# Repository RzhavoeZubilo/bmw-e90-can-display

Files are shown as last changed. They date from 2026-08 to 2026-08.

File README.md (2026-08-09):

# BMW E90 PT-CAN Display

Дополнительная приборка на Arduino Nano. Пассивно слушает моторную шину
PT-CAN и выводит на OLED температуры охлаждающей жидкости, масла двигателя и
**масла АКПП** и напряжение бортсети. При перегреве двигателя или коробки
мигает светодиодом и пищит.

## Целевая машина

**BMW E90 318i, 2011 (LCI), N46B20 бензин, АКПП ZF 6HP19.**

Что из этого следует:

- **N46 бензиновый → температура масла двигателя доступна.** Пустой байт `0xFF`
  в `0x1D0` — особенность дизелей N47, к вам не относится.
- **ZF 6HP19 совпадает с эталонным стендом**, с которого сняты захваты в
  DBC-mega-merge; эталонные логи сняты с E90 LCI — то же поколение.
- **2011 год → на контактах 6/14 колодки D-CAN**, а не PT-CAN. Переход
  произошёл около 03/2007. К PT-CAN подключаемся не через OBD (см. ниже).

## Быстрый старт

```bash
export PATH="$PATH:$HOME/.platformio/penv/bin"   # добавьте в ~/.zshrc
```

| Задача | Команда |
|---|---|
| Юнит-тесты на Mac (без железа) | `pio test -e native` |
| Сборка боевой прошивки | `pio run` |
| Прошивка | `pio run -t upload` |
| Разведка шины | `pio run -e sniffer -t upload` |
| Монитор порта | `pio device monitor` |
| Симулятор дисплея (картинка) | `./sim/build.sh` |

## Шины E90 и что на какой лежит

Три шины, на глаз неразличимые:

| Шина | Скорость | Что даёт |
|---|---|---|
| **PT-CAN** | 500 кбит/с | мотор, EGS, **температура масла АКПП** |
| K-CAN | 100 кбит/с | кузов, приборка, топливо по бакам, кнопки руля |
| D-CAN | 500 кбит/с | диагностика, молчит пока не спросят |

Устройство сделано под **PT-CAN**: только там вещается температура масла
коробки (`0x0B5`, сигнал `TEMP_GRB`). Подключение — два провода к CAN H и
CAN L в любом удобном месте: блок JBE, CAS, разъём у коробки.

| Параметр | Где | Состояние |
|---|---|---|
| Температура ОЖ | `0x1D0` B0 | работает |
| Температура масла двигателя | `0x1D0` B1 | работает (бензин) |
| **Температура масла АКПП** | `0x0B5` B7 | **работает** |
| Напряжение бортсети | `0x3B4` | работает |
| Температура впуска | не найдено на PT-CAN | **разведка** |
| Топливо | `0x349` — это K-CAN | **разведка** |

Топливо по бакам в литрах есть только на K-CAN, температуры впуска в нашем
DBC нет вообще. Места в вёрстке под оба параметра готовы и заняты прочерками.

### Как достать недостающее

На PT-CAN, помимо вещания, есть **адресный UDS-канал** к блокам напрямую:

| Блок | Запрос | Ответ |
|---|---|---|
| DME (двигатель) | `0x600` | `0x608` |
| EGS (ZF 6HP19) | `0x604` | `0x60C` |
| DSC (ABS) | `0x612` | `0x61A` |

Туда шлётся сервис UDS `0x22` с идентификатором данных. По DBC, `0x60C`
держит адаптации коробки и калибровки температуры ATF. Идентификаторы
публично не документированы — нащупываются сканером на живой машине.

## Разведка перед установкой

Пошаговая инструкция для работы на машине — от проверок на столе до
подключения к PT-CAN: **[docs/field-test.md](docs/field-test.md)**.

```bash
pio run -e sniffer -t upload && pio device monitor
```

Сканер дважды по 10 секунд слушает молча — на 100 и на 500 кбит/с, потому что
на неверной скорости любая шина выглядит немой. Затем печатает словарь ID и
сверяет его с маркерами известной принадлежности:

```
0x1D0   412   8B FF 6A C8 ...   <- [B] EngineData coolant/oil
0x0B5   205   00 00 .. .. 78    <- [P] EGS torque + ATF temp
markers: PT-CAN-only 1, K-CAN-only 0
=> PT-CAN. lib/PtCan decoders apply. ATF temp available.
```

`[P]` — только PT-CAN, `[K]` — только K-CAN, `[B]` — есть на обеих (DME
вещает, шлюз ретранслирует). Дальше свип стандартных PID `0x00..0xA0`.

## Структура

```
include/pins.h          распиновка, единственное место с номерами ног
lib/PtCan/              декодер PT-CAN — используется прошивкой
lib/Screen/             вёрстка экрана на C-API u8g2, общая с симулятором
lib/Alerts/             пороги предупреждений
lib/BtnLearn/           поиск кнопки руля в потоке кадров
lib/KCan/               декодер K-CAN — резерв, если переедем на кузовную шину
lib/Obd/                клиент OBD-II — резерв, если вернёмся к колодке
lib/Buttons/            антидребезг — резерв под кнопки
src/main.cpp            склейка железа: приём, отрисовка, индикация
src/sniffer.cpp         разведка шины и свип PID
docs/field-test.md      инструкция по разведке на машине
docs/enclosure.md       эскиз корпуса под 3D-печать
docs/wiring.md          распайка и порядок сборки
docs/components.md      справка по компонентам и работе с ними
docs/cluster-menu.md    скрытое меню приборки: что показывает штатно
docs/rad2-coding.md     магнитола RAD2: почему не кодируется, индексы
docs/references.md      внешние источники и что каждый дал
docs/diag-jobs.md       запросы к блокам, извлечённые из SP-Daten
tools/sgbd_extract.py   извлекатель телеграмм из SGBD
cad/enclosure.scad      параметрическая модель корпуса (OpenSCAD)
sim/                    симулятор дисплея для macOS
test/                   нативные тесты (49 шт.)
```

Всё, что имеет смысл тестировать, лежит в `lib/` и не зависит от Arduino,
поэтому `pio test -e native` выполняется прямо на Mac за пару секунд. `src/` —
тонкий слой поверх железа, он не тестируется.

`lib/KCan`, `lib/Obd` и `lib/Buttons` в текущую прошивку не линкуются и флеш
не занимают, но покрыты тестами и готовы к подключению.

### Откуда взяты определения сигналов

Из репозитория **DBC-mega-merge** (`bmw_e9x_e8x1_merged.dbc`), лежащего рядом
в `../DBC-mega-merge`. Это сведённый DBC по E8x/E9x, собранный из opendbc,
loopybunny.co.uk и форумных источников и дополненный захватами с живой машины
и HIL-стенда.

Кадры DME проверены тестами на **реальных байтах** из
`tools/known_values.json` — это самые частые значения из логов:

| Кадр | Захваченные байты | Результат декодера |
|---|---|---|
| `0x1D0` | `8B FF 6A C8 ...` | ОЖ 91 °C, масло отсутствует (`0xFF`, N47) |
| `0x3B4` | `CB F3 00 FC ...` | 14.57 В |

Кадр EGS `0x0B5` на K-CAN не выходит, поэтому байтов с живой машины у нас
нет: его декодер проверен **только по DBC** — разрядность, смещение и
формула. Это единственная непроверенная эмпирически часть.

Полезные соседи по теме [github.com/topics/e90](https://github.com/topics/e90):

| Репозиторий | Чем полезен |
|---|---|
| `veikkos/e90-can-cluster` | распиновка разъёма приборки, предупреждение про терминатор |
| `Maseg535/E90-and-e8x-DBC-mega-merge-project` | тот самый DBC, который мы используем |
| `ilicmiljan/open-can-controller` | управление приборкой E9x по K-CAN через KWP2000 |

## Распиновка

| Ножка | Назначение | Примечание |
|---|---|---|
| D2 | MCP2515 INT | нужен именно D2 или D3 (INT0/INT1) |
| D6 | WS2812B DIN | один диод |
| D9 | KY-006 зуммер | пассивный, работает через `tone()` |
| D10 | MCP2515 CS | |
| D11/D12/D13 | SPI MOSI/MISO/SCK | аппаратный SPI, не переназначить |
| A4 / A5 | I2C SDA / SCL | OLED, адрес 0x3C |
| D3, D4, D5, D7 | резерв под TTP-223 | не используется |

Питание: один Mini360 с 12 В бортсети на 5 В. Второй модуль, четыре кнопки,
четыре светодиода из пяти и BME280 — запас на будущее, в сборке не участвуют.

Полная распайка, цепочка питания и порядок первого включения —
**[docs/wiring.md](docs/wiring.md)**.

Компоновка в корпусе под 3D-печать — **[docs/enclosure.md](docs/enclosure.md)**:
план дна, разрез, крышка и настройки печати.

## Симулятор дисплея

```bash
./sim/build.sh          # -> sim/out/screens.png
```

Рисует все состояния экрана в картинку, без железа и без машины. Это не макет:
симулятор гоняет **тот же самый `lib/Screen`**, что и прошивка, поверх C-ядра
u8g2, собранного под macOS. Разъехаться с реальным выводом он не может по
построению.

На AVR u8g2 рисует по страницам в буфер на 128 байт, на хосте — в полный буфер
128×64, куда симулятор заглядывает напрямую. Дисплей и шина не нужны, колбэки
вывода заглушены. Дальше буфер раскрашивается по физическому делению матрицы:
строки 0–15 жёлтым, 16–63 синим.

Именно поэтому `lib/Screen` написан на **C-API u8g2**, а не на Arduino-обёртке
`U8g2lib.h`: C-ядро переносимо, а обёртка тянет за собой `Print` и весь
Arduino. Побочная выгода — форматирование чисел там сделано вручную, без
`sprintf`, который на AVR стоит около полутора килобайт.

Сценарии перечислены в `build_scenarios()` в `sim/sim_main.cpp`. Первая сборка
компилирует C-ядро u8g2 и кэширует объектники в `sim/out/`, дальше мгновенно.

## Грабли

Собрано по ходу разработки. Большинство пунктов стоили бы вечера отладки.

### Без аппаратных фильтров MCP2515 кадры теряются молча

PT-CAN на 500 кбит/с даёт порядка 1500–2000 кадров в секунду. У MCP2515 два
приёмных буфера, и Nano разгребает их по SPI — без фильтров переполнение
гарантировано, причём **без единого признака в логах**.

Прошивка настраивает маски `0x7FF` (точное совпадение всех 11 бит) и все шесть
фильтров. Нужных ID сейчас три, остальные фильтры дублируют последний: пустой
фильтр пропускал бы всё подряд. Три свободных — запас под то, что найдёт
разведка. Список в `kWanted` в `src/main.cpp`.

### FastLED.show() нельзя дёргать в каждом проходе loop()

На AVR `show()` запрещает прерывания на всё время передачи данных в ленту.
Если вызывать его безусловно каждый проход, процессор проводит с
запрещёнными прерываниями почти всё время. Последствия неочевидные и
неприятные: **начинает отставать `millis()`** — а на нём висит вся логика
протухания данных, — ломается `tone()`, которому нужен таймерный ISR, и
страдает приём по I2C.

Правильно — вызывать только при смене состояния светодиода. Мигание с
периодом 400 мс даёт пару вызовов в секунду вместо тысяч. Реализовано в
`update_alerts()` в `src/main.cpp` через сравнение с прошлым состоянием.

### Сторожевой таймер и загрузчик

`wdt_enable(WDTO_2S)` в конце `setup()`, `wdt_reset()` в начале `loop()`.
Устройство живёт в машине без присмотра, зависший блок там никто не
перезагрузит.

Работает это безопасно **только потому, что плата на новом загрузчике**
(Optiboot, `board = nanoatmega328new`): он сбрасывает флаг `WDRF` и снимает
таймер при старте. Со старым загрузчиком срабатывание сторожевого таймера
загоняло плату в бесконечную перезагрузку, и спасала только перепрошивка
программатором.

В `sniffer` сторожевой таймер намеренно не включён: его фазы переписи длятся
по 10 секунд в одном блокирующем цикле, и таймер пришлось бы сбрасывать
изнутри. Инструмент запускается под присмотром, смысла в нём нет.

### Терминатор 120 Ом на модуле MCP2515 надо снять

Дешёвые платы приходят с напаянным резистором 120 Ом между CAN H и CAN L. Он
нужен при построении шины с нуля и **вреден при подключении к существующей**:
у исправной шины уже есть два своих терминатора, суммарно 60 Ом. Третий
опускает сопротивление до 40 Ом, и связь начинает сыпаться.

Симптом коварный: работает «через раз» или падает при прогреве. Проверяется
мультиметром на обесточенном модуле между CAN H и CAN L — увидите ~120 Ом,
резистор надо выпаять (на части плат вместо него перемычка).

Источник: README проекта
[veikkos/e90-can-cluster](https://github.com/veikkos/e90-can-cluster) —
«There should NOT be 120 Ohm termination in the CAN bus adapter».

### mcp_can хочет `unsigned long`, а не `uint32_t`

`readMsgBuf()` объявлен как `readMsgBuf(INT32U *id, ...)`, где `INT32U` — это
`unsigned long`. На AVR `uint32_t` и `unsigned long` — один и тот же тип,
поэтому `uint32_t id` собирается без нареканий, **но**:

- IntelliSense в VS Code разбирает файл в модели хоста, где `uint32_t` это
  `unsigned int`, и ругается «нет перегрузки» при зелёном `pio run`;
- на STM32 и ESP32 `uint32_t` тоже `unsigned int`, и там это станет настоящей
  ошибкой компиляции.

Поэтому во всех вызовах переменная объявлена как `unsigned long`. Правка
`.vscode/c_cpp_properties.json` не помогает: файл генерируется заново.

### MCP2515: кварц 8 или 16 МГц

В `platformio.ini` стоит `-D MCP2515_CRYSTAL_MHZ=8`. Дешёвые платы выпускают
с обоими кварцами — **посмотрите маркировку на кристалле** и поправьте флаг.
При неверном значении тайминги бит-рейта считаются неправильно, и CAN либо не
поднимется, либо будет сыпать мусором.

### Байт масла двигателя может быть `0xFF`

На дизелях N47 `0x1D0` B1 всегда `0xFF`. Наивная формула `raw - 48` дала бы
207 °C и постоянную ложную тревогу перегрева, поэтому декодер это значение
отбрасывает. На вашем N46 байт должен быть живым.

### Жёлто-синий OLED: граница на строке 16

Двухцветность физическая, а не программная: строки 0–15 всегда жёлтые, 16–63
всегда синие, границу не подвинуть. Крупный шрифт, поставленный без учёта
этого, разрезается пополам и выглядит как брак.

Вёрстка это учитывает: жёлтая полоса отдана под статус, все данные лежат
целиком ниже строки 16, четыре строки с baseline 27 / 38 / 49 / 60.

### tone() и FastLED делят прерывания

`tone()` на AVR всегда занимает Timer2 независимо от выбранной ноги, а
`FastLED.show()` кратко запрещает прерывания. На одном диоде пауза мизерная,
но если услышите щелчки в писке — причина здесь.

### Mini360 настраивается до подключения нагрузки

Подстроечник выставляется **до** того, как к выходу подключена электроника.
Иначе на выходе может оказаться входное напряжение, и Nano вместе с дисплеем
уходит в утиль за секунду.

### Прочее

- Плата с TYPE-C и CH340 — почти всегда **new bootloader** (115200), отсюда
  `board = nanoatmega328new`. Со старым `nanoatmega328` прошивка не зальётся.
- Если порт не появляется в `ls /dev/cu.*`, нужен драйвер CH340:
  `brew install --cask wch-ch34x-usb-serial-driver`.
- Основная прошивка не открывает Serial и **ничего не передаёт в шину**
  (`MCP_LISTENONLY`). Для отладки пользуйтесь env `sniffer`.

## Память

```
RAM:   54.4% (1114 / 2048)
Flash: 60.5% (18580 / 30720)
```

Запаса ~12 КБ флеша. Полнокадровый режим U8g2 (буфер 1024 байта) на Nano не
помещается, поэтому используется page-режим: буфер 128 байт, отрисовка циклом
`firstPage()/nextPage()`.

### Что сколько стоит

Замерено на этом проекте, каждый пункт — отдельная сборка:

| Что | Flash |
|---|---|
| Библиотека FastLED | **3018 байт** |
| Печать `float` (`print(x, 1)`) | **758 байт** |
| Крупный шрифт `logisoso20_tn` | 402 байта |
| `Serial.begin()` | 106 байт |

FastLED — самый дорогой компонент, и это плата за **саму библиотеку**, а не за
диоды: каждый стоит 3 байта RAM, разница между одним и пятью — двенадцать
байт. Для единственного светодиода 3 КБ расточительно; альтернатива — ручной
бит-бэнг WS2812 примерно на 100 байт, но там критичные тайминги.

Печать float тянет `dtostrf`. В проекте она не используется: значения хранятся
целыми в десятых долях и печатаются вручную.

### Стоит ли покупать «расширение памяти»

**Нет — для этой задачи такого модуля не существует.** ATmega328P построен по
гарвардской архитектуре и выполняет код **только из внутренней флеш-памяти**.
SD-карта, EEPROM, SPI-флешка хранят *данные*, а не исполняемый код.

Если проект перерастёт 32 КБ, вариант один — сменить плату:

| Плата | Флеш / RAM | Что переделать |
|---|---|---|
| **Mega 2560 Pro Mini** | 256 КБ / 8 КБ | только номера ног, логика 5 В |
| **STM32F103 «Blue Pill»** | 64–128 КБ / 20 КБ | встроенный CAN, логика 3.3 В |
| **ESP32** | 4 МБ / 520 КБ | встроенный CAN, Wi-Fi, логика 3.3 В |

При нынешних 60 % это теоретически.

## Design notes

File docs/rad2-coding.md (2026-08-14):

# Магнитола RAD2: почему не кодируется через D-CAN

Тема соседняя с основным проектом — здесь про кодирование головного
устройства, а не про наш прибор. Лежит в этом репозитории, потому что
собрано теми же инструментами и по тем же данным.

**Блок:** BMW Radio Professional CD, `6512 9258170-01`, `BMWRCD 202-35`,
Bluetooth, Чехия, 04/2011. Машина: E90 318i 2011 LCI.

**Симптом:** `SG_CODIEREN` и даже `CODIERDATEN_LESEN` в NCS Expert падают с
«ошибка CABD! смотри CABI.ERR und ERROR.LOG». Считается, что блок кодируется
только через ICOM.

---

## ⚠️ Поправка: причина ошибки другая

Изначальный диагноз в этом документе — «CABD не находит `RAD2.C34`» — **был
неверным**. Реальный текст ошибки, полученный позже:

```
COAPI-2020: SG antwortet nicht
IFH-0009: SG nicht angeschlossen oder meldet sich nicht   RAD2
```

`SG antwortet nicht` — «блок не отвечает». `IFH-0009` — ошибка обработчика
интерфейса EDIABAS, означающая, что ответа от блока не пришло вовсе.

То есть это **отказ связи, а не разбора данных**. Строка «Ошибка в CABD» —
всего лишь обёртка NCS Expert; настоящая причина напечатана под ней. Отсюда
же объяснение, почему не нашёлся `CABI.ERR`: CABD не дошёл до сборки данных
и своей ошибки не создавал.

Определение семейства `RAD22.C34` ниже остаётся верным и пригодится, когда
связь заработает, — но причиной этой ошибки оно не было.

### Рабочая гипотеза

Головное устройство на E90 сидит на **K-CAN**, а не на диагностической
D-CAN, и доступ к нему идёт **через шлюз**. В каталоге SGBD рядом с
`RAD2.prg` лежит **`RAD2_GW.prg`** — суффикс `GW` почти наверняка означает
вариант, работающий через шлюз.

NCS Expert использовал `RAD2.PRG`. Если прямой вариант адресует блок так,
как работает только внутри K-CAN, а `_GW` идёт через шлюз, это ровно та
разница, которая объясняет «через ICOM работает, через D-CAN нет».

**Не проверено** — требует запуска на машине.

### Порядок проверки

1. **Убедиться, что интерфейс вообще жив.** Tool32, загрузить `KOMB87.prg`,
   выполнить `IDENT`. Ответил — кабель и EDIABAS исправны, проблема
   именно в RAD2.
2. **Попробовать `RAD2_GW.prg`** в Tool32, тот же `IDENT`. Ответил там, где
   `RAD2.prg` молчит — гипотеза подтверждена, и дальше вопрос лишь в том,
   чтобы указать этот SGBD в профиле NCS Expert.
3. Если молчат оба — магнитола в вашей конфигурации по D-CAN недостижима, и
   ICOM остаётся единственным путём.

Tool32 здесь удобнее NCS Expert тем, что SGBD выбирается вручную, а не
берётся из профиля.

Проверить, что зажигание включено и магнитола не спит, — обязательное
условие для всех трёх пунктов.

---

## Определение семейства данных

**Блок относится к семейству данных `RAD22`, а не `RAD2`.**

Трейс `FSW_PSW`, снятый через ICOM, прогнан через парсер данных кодирования
и сопоставлен со всеми 339 файлами `.Cxx` для кузова E89:

| Файл данных | Совпадение с трейсом |
|---|---|
| **`RAD22.C34`** | **81.4 %** |
| `RAD22.C32` | 73.5 % |
| `RAD22.C31` | 62.8 % |
| `RAD22.C33` | 61.9 % |
| `RAD22.C20` | 43.4 % |
| `RAD2.C03/04/50/51` | **ниже порога, в кандидаты не попали** |

Из 113 строк трейса 92 совпали с `RAD22.C34` по именам параметров; остальные
21 — это не параметры, а их значения (`E90_HIFI`, `E81_TOP_HIFI` и подобные),
которые в трейсе идут отдельными строками.

Иначе говоря: **это `RAD22` с индексом кодирования 34.**

### Почему тогда CABD

Файлы данных кодирования именуются `<семейство>.C<индекс>`. В каталоге лежат:

```
RAD2.C03   RAD2.C04   RAD2.C50   RAD2.C51
RAD22.C20  RAD22.C31  RAD22.C32  RAD22.C33  RAD22.C34
```

**`RAD2.C34` не существует.** Если NCS Expert выбирает для этого блока
семейство `RAD2` (по профилю или по имени SGBD — `RAD2.prg` в каталоге есть,
а `RAD22.prg` нет), то при индексе 34 он ищет несуществующий файл. CABD не
может собрать данные и падает.

### Почему это не про кабель

**ICOM против K+DCAN — разница транспорта, а не логики кодирования.** NCS
Expert работает через EDIABAS, а тот умеет оба интерфейса. Если бы дело было
в железе, ошибка была бы коммуникационной: нет ответа, таймаут.

Решающий довод: падает и `CODIERDATEN_LESEN`. Чтение безобидно, блок его не
запрещает. Значит отказывает не блок, а разбор данных **на компьютере**, до
всякого обмена с машиной. CABD — компонент ПК.

ICOM «работает» потому, что ISTA-P везёт свои данные и сам выбирает нужное
семейство.

---

## Что проверить на машине

1. **Прочитать `CABI.ERR` и `ERROR.LOG`.** Сообщение прямо на них указывает,
   и там обычно назван конкретный отсутствующий файл. Это подтвердит или
   опровергнет диагноз за минуту.
2. **Прочитать индекс кодирования блока** — job `C_CI_LESEN` через Tool32.
   Чтение, риска нет. Ожидаемое значение — 34.
3. **Проверить, какую версию SP-Daten видит NCS Expert.** На диске лежат
   67.1 и 69.0; `RAD22.C34` найден в 69.0.

Если `C_CI_LESEN` вернёт 34, а NCS Expert ищет `RAD2.C34` — диагноз
подтверждён, и вопрос сводится к тому, чтобы указать ему семейство `RAD22`.

---

## Расшифровка индексов кодирования

Индексы идут по возрастанию функциональности. Ниже — что добавляет каждый
следующий относительно предыдущего.

| Индекс | Опций | Что появляется |
|---|---|---|
| `RAD2.C03` | 55 | базовый набор |
| `RAD2.C04` | 57 | `M_GROUP`, `USB_RAD2` |
| `RAD2.C50` | 75 | гонги, `COUNTRYCODE_RADIO_2`, концепция микширования |
| `RAD2.C51` | 81 | `MCA`, `BASS_MSA`, навигационные уровни |
| `RAD22.C20` | 70 | маршрутизация звука, лимитеры, `AUX_RAD22` |
| `RAD22.C31` | 83 | **INBOX-группа**: Bluetooth, распознавание речи, `DAB_INBOX`, микрофон |
| `RAD22.C32` | 86 | `SECOND_USB`, `RAD22_MDRIVE`, параметры с суффиксом `_32` |
| `RAD22.C33` | 83 | вариант C32 с суффиксом `_B` вместо `_32` |
| **`RAD22.C34`** | **94** | `DAB_STANDARD_RAD` (DAB+), `CALL_WAITING_INBOX`, `FADER`, `COLORSWITCH_E84` |

Быстрые признаки принадлежности:

| Параметр | Встречается в |
|---|---|
| `BT_MODUL_INBOX_ON_OFF`, `MICROPHONE_INBOX`, `DAB_INBOX` | C31, C32, C33, C34 |
| `SECOND_USB` | C32, C34 |
| `DAB_STANDARD_RAD`, `CALL_WAITING_INBOX`, `COLORSWITCH_E84` | **только C34** |

В вашем трейсе есть `DAB_STANDARD_RAD = dab_plus`, `CALL_WAITING_INBOX` и
`SECOND_USB` — то есть однозначно **C34**, самый поздний индекс из
имеющихся. Что согласуется с датой выпуска 04/2011.

---

## Про вывод параметров на экран магнитолы

Ответ тот же, что был по приборке: **магнитола показывает только то, что
умеет её прошивка**, а кодирование лишь выбирает из готового набора. Вывести
туда наши значения — температуру масла АКПП, впуск — нельзя без правки
прошивки.

Штатные пункты (средний расход, забортная) включаются кодированием. В вашем
трейсе видны кандидаты:

| Параметр | Текущее значение |
|---|---|
| `CAR_COMP_ACTIVE` | `aktiv` |
| `V_INFO_RAD2` | `nicht_aktiv` |
| `MY_INFO_RAD2_20` | `nicht_aktiv` |

Что именно за ними стоит — надо смотреть в описании функций; имена
параметров в SWT-словарях даны без развёрнутых пояснений.

**Осторожно:** `20.00`-подобные параметры и всё, что меняет уровни и
лимитеры, — это запись в блок. Читать безопасно, писать нет, а у вас уже
есть рабочий путь через ICOM.

---

## Как воспроизвести разбор

```bash
cd /Users/densh/Work/Develop/BMW/BimmerDaten
python3 - <<'EOF'
import sys; sys.path.insert(0,'.')
from daten_parser import parse_trc, detect_module_from_trc
D = ".../BMW SP-Daten 69.0/E89/daten"
trc = parse_trc("путь/к/FSW_PSW.TRC")
for f, r in detect_module_from_trc(set(trc.keys()), D, ""):
    print(f, f"{r*100:.1f}%")
EOF
```

Парсер шумит в stderr на части посторонних файлов — это не мешает, вывод
берётся из stdout.

Словари имён: `SWTFSW03.dat` (функции) и `SWTPSW03.dat` (значения) в том же
каталоге `daten`.

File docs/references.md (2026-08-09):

# Внешние источники

Что использовано по ходу работы и что именно каждый источник дал. Полезно
тем, что видно, какие выводы подтверждены независимо, а какие держатся на
одном источнике.

---

## Данные о шине

### DBC-mega-merge

`github.com/Maseg535/E90-and-e8x-DBC-mega-merge-project`, клон лежит в
`../DBC-mega-merge`. Сведённый DBC по E8x/E9x: 386 сообщений, 430 сигналов,
плюс захваты с живой машины и HIL-стенда.

**Дал:** все определения в `lib/KCan` и `lib/PtCan`. Файл
`tools/known_values.json` содержит самые частые байты по каждому ID — на них
построены тесты декодеров.

**Ограничения:** 275 сообщений из 386 без единого сигнала; 104 ID встречаются
в логах, но в DBC отсутствуют вовсе. Сами логи в репозиторий не попали, есть
только выжимка, по которой нельзя восстановить ни периоды, ни корреляции.

### loopybunny.co.uk/CarPC

Справочник по K-CAN E90. **В DBC уже поглощён** — указан там источником
десяти сигналов, включая скорость, двери, климат, поворотники.

Отдельная страница про интерфейс конкретики не содержит: перечислены Arduino
и MCP2515, но ни распиновки, ни точек подключения, ни требований по
терминированию там нет.

### SP-Daten 69.0 + BimmerDaten

Заводские описания диагностики. Декодер `.prg` — `decoderPrg.py`, парсер
данных кодирования — `daten_parser.py`.

**Дал:** телеграммы запросов ко всем блокам (см. [diag-jobs.md](diag-jobs.md)),
подтверждение диапазона температуры ATF, диагноз проблемы с кодированием
магнитолы (см. [rad2-coding.md](rad2-coding.md)).

---

## Чужие устройства того же назначения

### Инструкция к серийному зеркалу-дисплею

Бумажная инструкция к готовому устройству для E9x/E7x/E8x.

**Дала:** точную точку подключения PT-CAN — блок **JBBF**, синяя фишка
**X14271**, контакт 1 = CAN H (синий/красный), контакт 2 = CAN L (красный).
Это то, чего не было ни в одном другом источнике.

Плюс идею обучения кнопки руля: устройство не знает ID заранее, а находит
его, наблюдая, какой бит меняется при удержании. Реализовано в `lib/BtnLearn`.

### veikkos/e90-can-cluster

`github.com/veikkos/e90-can-cluster` — Arduino, управляющий приборкой E90.

**Дал:** распиновку 18-контактного разъёма приборки (pin 6 CAN H, pin 7
CAN L, pin 9 12 В, pin 18 GND) и предупреждение про терминатор:
«There should NOT be 120 Ohm termination in the CAN bus adapter».

### Серия записей на drive2 (E90 2007, дизель M57)

Три записи одного автора: то же по смыслу устройство на ESP32, три итерации
от 2,4″ до 5″ дисплея DWIN.

**Подтверждает независимо:**

| Вывод | Как подтверждён |
|---|---|
| На OBD-разъёме широковещания нет | автор пришёл к тому же и ушёл к приборке |
| Две шины: K-CAN 100, PT-CAN 500 | названы прямо теми же цифрами |
| `0x3B4` = напряжение, первые 2 байта | совпадает с нашим декодером |
| Терминатор 120 Ом надо снимать | у него SN65HVD230 с выпаянным резистором |
| `0x2FC` двери | совпадает с DBC |

**Новое, чего у нас не было:**

- **Засыпание по шине.** Устройство включается по зажиганию и выключается,
  когда шина сообщает об отсутствии ключа. Лучше, чем искать цепь после
  зажигания — см. [wiring.md](wiring.md).
- **Многозначные ответы.** Он отмечает, что диагностические сообщения пакуют
  несколько параметров в один ответ, и за счёт этого держит ~30 параметров
  каждые 100 мс. Мы видели то же в SGBD: `STATUS_TANKINHALT` возвращает пять
  значений за один запрос.
- **K-line как параллельный канал** для того, чего нет в широковещании. Нам
  недоступен: у него машина 2007 года, на нашей 2011 K-line заменён на D-CAN
  (переход около 03/2007).

Точку подключения он искал долго — плафон салона, блок света, топливный
насос — и в итоге сел на комбинацию приборов. У нас эта задача решена
инструкцией к серийному устройству, точка известна сразу.

---

## Реверс прошивок приборки

`../прошивки приборок` — собственный проект владельца: разбор прошивок KOMBI
(Siemens VDO PL2, Fujitsu MB90F395HA, F2MC-16LX) с самописным
дизассемблером.

**Дал:** понимание, что прошивка приборки содержит авторитетные распаковщики
принимаемых ею кадров — найден распаковщик `0x1D2`. Это принципиально более
надёжный источник определений, чем корреляция по логам.

**Упирается в:** подпись флеша (`FLASH_SIGNATUR_PRUEFEN`), из-за которой
модифицированный образ обратно не зальётся. Отмечено самим автором как
нерешённое.

---

## Что подтверждено сколькими источниками

| Вывод | Источников |
|---|---|
| OBD-разъём не даёт широковещания | 3: DBC, инструкция, drive2 |
| Терминатор 120 Ом мешает | 2: veikkos, drive2 |
| `0x1D6` = кнопки руля | 3: DBC, SGBD DSC, drive2 (косвенно) |
| `0x3B4` = напряжение | 2: DBC (захваты), drive2 |
| Температура ATF в `0x0B5` | 2: DBC, SGBD ZF (диапазон) |
| Раскладка ответа DME на впуск | **0 — только вывод из порядка полей** |
| Кнопки руля доступны на PT-CAN | 1: SGBD DSC, на машине не проверено |

Последние две строки — то, что стоит проверить в первую очередь.

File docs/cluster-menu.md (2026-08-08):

# Скрытое меню приборки

Штатное сервисное меню KOMBI. Открывается удержанием кнопки сброса суточного
пробега при включённом зажигании; большинство разделов требует разблокировки
через пункт `19.00`, а тест индикации `02.00` доступен и без неё.

**Статус: большинство пунктов проверено владельцем на этой машине** (E90 318i
2011, N46B20, ZF 6HP19). Нумерация у разных комплектаций может отличаться.

---

## Почему это важно для проекта

Меню показывает **часть того же набора, что и наше устройство**, причём без
единого провода. Это меняет ответ на вопрос «зачем вообще нужен прибор».

| Пункт | Параметр | Есть ли у нас |
|---|---|---|
| `07.00 KTMP-MOM` | температура ОЖ | экран 2 |
| `06.00 TANK L R S` | топливо: левый, правый, сумма | **нет**, не смогли достать |
| `06.02 TANK-OHM L R` | сопротивления датчиков баков | нет |
| `09.00 UB` | напряжение бортсети | экран 3 |
| `07.01 ATMP-MOM` | забортная температура | нет |
| `07.03 N-MOT-MOM` | обороты | убрано намеренно |

### Чего в меню нет

**Температуры масла АКПП и температуры впуска.** Ни в одном пункте. Это
ровно то, что даёт устройство и не даёт машина.

Плюс постоянная видимость: меню нужно открывать и листать, а экран висит
перед глазами и сам пищит при перегреве. Но список, где устройство
действительно уникально, — два параметра, а не семь. Стоит понимать честно.

---

## ★ Калибровка баков

Мы отказались от чтения `STATUS_TANKINHALT` у приборки в том числе потому,
что **масштаб ответа неизвестен**: в SGBD у результатов написано просто
«Zahlenwert», а единица возвращается отдельной строкой во время выполнения
(см. [diag-jobs.md](diag-jobs.md)).

Меню эту неизвестность снимает. Пункты `06.00` и `06.02` показывают те же
датчики в литрах и в омах.

Процедура:

1. Открыть `06.00`, записать литры по левому и правому датчику.
2. Тут же отправить приборке `21 0A` и записать **сырой ответ**.
3. Повторить при заметно другом уровне топлива — две-три пары дадут и
   множитель, и смещение.

Одного замера хватит на множитель, если смещение нулевое; два замера решают
систему полностью. То есть блокирующая неизвестность устраняется за один
подход к машине — при условии, что до KOMBI получится дотянуться по шине,
а это отдельный вопрос (приборка на K-CAN).

---

## Прочее полезное

`02.00 KI TEST` — прогон стрелок и индикаторов, **доступен без
разблокировки**. Это та самая функция, которую серийное устройство из
инструкции подаёт как своё умение; на деле для неё ничего не нужно.

`15.xx PORT xxh` — значения портов контроллера в битах. Готовое окно в
состояние железа для разбора прошивки приборки.

`14.xx FSPxx` — записи в памяти ошибок, без диагностического сканера.

`20.00 KORR-VERBR` — коэффициент коррекции расхода. **Это запись, а не
чтение**: пункты `20.01`–`20.03` меняют значение по разрядам.

---

## Полный список

| Пункт | Обозначение | Что это |
|---|---|---|
| 01.00 | FGSTNR | VIN приборки |
| 01.01 | K-ZAHL W/T | корректировка пробега |
| 01.02 | BMWTNR | серийный номер приборки |
| 01.03 | COD DIA | код диагностики |
| 01.04 | KI HSTLDATUM | дата производства |
| 01.05 | HW AEI | версия железа |
| 01.06 | SW | версия прошивки |
| 01.07 | KODIERDATEN | данные кодирования |
| 01.08 | CAN | версия шины |
| **02.00** | **KI TEST** | **тест индикации, без разблокировки** |
| 03.00 | UNBELEGT | не используется |
| 04.00 | VERB-MOM | мгновенный расход, л/100 км |
| 04.01 | VERB-MOM | мгновенный расход, л/час |
| 04.02–04.05 | D-VERB1/2 | средний расход и дистанция поездок |
| 05.00 | RW-VERB | средний расход для запаса хода |
| 05.01 | RW-MOM | запас хода |
| **06.00** | **TANK L R S** | **топливо: левый, правый, сумма** |
| 06.01 | TANK-ANZ PH | общее количество в баке |
| **06.02** | **TANK-OHM L R** | **сопротивления датчиков, Ом** |
| **07.00** | **KTMP-MOM** | **температура ОЖ** |
| 07.01 | ATMP-MOM | забортная температура |
| 07.02 | ATMP ADC | сырое значение датчика забортной |
| 07.03 | N-MOT-MOM | обороты двигателя |
| 07.04 | N-VWF-MOM | ограничитель оборотов при прогреве, M-серия |
| 08.00 | V-EFF | скорость на колёсах |
| 08.01 | V-ANZ | скорость на индикаторе |
| 08.02 | V-SZ | заданная скорость круиза |
| 08.03–08.06 | DGESCH1/2 | расстояние и время поездок |
| **09.00** | **UB** | **напряжение бортсети** |
| 10.00 | KM / WOCHE | пробег за неделю |
| 10.01–10.04 | CBS | сервисные счётчики |
| 11.00–11.03 | EINH | форматы: время, расстояние, температура, расход |
| 12.00 | V-ANKUNFT | скорость для расчёта прибытия |
| 12.01 | ANK-ZEIT | время до прибытия |
| 13.00 | AUDIO | тест сервисных звуков |
| 14.00 | FS-EINTRAEGE | количество ошибок в памяти |
| 14.xx | FSPxx | запись об ошибке |
| **15.xx** | **PORT xxh** | **значение порта в битах** |
| 16.00 | DIMMRAD-CAN | текущая яркость подсветки по шине |
| 16.01 | PHOTO-ADC | датчик света |
| 16.02–16.03 | DIMM-PWM | ШИМ подсветки |
| 17.00 | DISP-HEIZ | нагрев дисплея |
| 17.01 | NTC1 NTC2 | термисторы |
| 17.03 | KONTR-PWM | ШИМ контрастности |
| 18.00 | CC-TEST? | тест Check Control |
| 19.00 | UNLOCK | разблокировка меню, повторный вызов блокирует |
| **20.00** | **KORR-VERBR** | **коэффициент коррекции расхода — запись** |
| 20.01–20.03 | KORR | разряды коэффициента |
| 21.00 | RESET? | сброс данных |

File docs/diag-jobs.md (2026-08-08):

# Диагностические запросы из SP-Daten

Всё, что не удалось получить из широковещания, достаётся диагностическими
запросами. Идентификаторы данных BMW публично не документированы, и мы
собирались нащупывать их, слушая трафик Tool32. Оказалось, что этого не
нужно: **телеграмма запроса лежит прямо в байткоде SGBD**.

Источник: SP-Daten 69.0, каталог `E89/ecu`. Декодер `.prg` —
[BimmerDaten](https://github.com/…/BimmerDaten), `decoderPrg.py`.

```bash
python3 tools/sgbd_extract.py ".../E89/ecu/KOMB87.prg" TANK
```

---

## Формат телеграммы

В дизассемблере job'а запрос выглядит так:

```
move  S1,{$82.B,$FF.B,$F1.B,$21.B,$0A.B}
             │     │     │     │     └── идентификатор данных
             │     │     │     └──────── сервис KWP2000
             │     │     └────────────── адрес тестера
             │     └──────────────────── адрес блока, подставляет EDIABAS
             └────────────────────────── формат: 0x80 | длина полезной части
```

Метод проверяется на job'е, где идентификатор продублирован в комментарии:
у `STATUS_TANKINHALT` написано «`$21 ReadDataByLocalIdentifier`, `$0A
Tankinhalt`», и извлечённая телеграмма `82 FF F1 21 0A` совпадает.

Байт `FF` — заглушка адреса блока, EDIABAS подставляет туда настоящий адрес
в момент выполнения; в самом `.prg` его нет. Значащая часть, не зависящая от
транспорта, — это **сервис и идентификатор**, последние два-три байта.

---

## Что нашлось для наших параметров

### Приборка — KOMB87

| Job | Запрос | Что возвращает |
|---|---|---|
| `STATUS_TANKINHALT` | `21 0A` | **литры датчика 1 и датчика 2**, сумма, сглаженная сумма, фаза бака |
| `STATUS_KLEMMENSPANNUNG` | `21 21` | напряжение питания приборки, мВ |
| `STATUS_A_TEMP_LESEN` | `21 22` | забортная: показание и сырое значение |

`STATUS_TANKINHALT` закрывает наш главный долг — **раздельные баки в литрах**.
На PT-CAN их нет, на K-CAN они в кадре `0x349`, а тут их можно просто
спросить у приборки. Возвращается и `Tankphase`: 1 — оба датчика исправны,
2 — хотя бы один неисправен.

### Коробка — GS19D (ZF 6HP19)

| Job | Запрос | Что возвращает |
|---|---|---|
| `STATUS_GETRIEBETEMPERATUR` | `21 01` | температура масла АКПП, **диапазон −40…215 °C** |
| `STATUS_MOTORTEMPERATUR` | `21 02` | температура двигателя по данным EGS |
| `STATUS_GETRIEBEPOSITION` | `21 18` | текущая позиция коробки |

Диапазон `−40…215` **в точности совпадает** с описанием сигнала `TEMP_GRB`
кадра `0x0B5` в DBC-mega-merge, на котором построен наш декодер `lib/PtCan`.
Это независимое подтверждение с заводской стороны: до сих пор декодер был
проверен только по DBC, без данных с живой машины.

SGBD подписан авторами из ZF — то есть это документация производителя
коробки, а не community-реверс.

### Двигатель — MEV17N46 (N46)

| Job | Запрос | Что возвращает |
|---|---|---|
| `STATUS_AN_LUFTTEMPERATUR` | `30 0A 01` | **температура впуска**, A2L-имя `tans` |
| `STATUS_UBATT` | `30 1C 01` | напряжение клеммы 87 |

Впуск — второй наш недостающий параметр. Обратите внимание на сервис: у DME
это `0x30`, а не `0x21`, и идентификатор двухбайтовый. Job отдаёт заодно
сырое напряжение АЦП датчика.

Для N46 в каталоге лежат `MEV17N46.prg` и `MEV9N46.prg` — какой из них ваш,
определяется по ответу на `IDENT`.

---

## ★ Job'ы, читающие шинные сообщения

У DSC нашлась группа `STATUS_F_CAN_*` с комментариями вида «Auslesen der CAN
Botschaft». Идентификатор запроса у них **равен CAN-ID кадра**:

| Job | Запрос | Кадр | Что декодирует |
|---|---|---|---|
| `STATUS_F_CAN_TASTER_AUDIO_TEL` | `22 01 D6` | **`0x1D6`** | шесть кнопок руля |
| `STATUS_F_CAN_TEMPOMAT_ACC` | `22 01 94` | `0x194` | подрулевой круиз, 9 полей |
| `STATUS_F_CAN_WISCHERTASTER` | `22 02 A6` | `0x2A6` | подрулевой стеклоочистителя |
| `STATUS_F_CAN_LW` | `22 01 18` | `0x118` | датчик угла руля, 11 полей |
| `STATUS_F_CAN_TYP_SENSORCLUSTER` | `22 01 40` | `0x140` | тип сенсорного кластера |

`0x1D6` разбирается на: Telefon, Audio Lautstärke, Audio Suchlauf, Push to
Hear, Sonderfunktion, Push to Talk. Это ровно те шесть кнопок, что описаны в
DBC-mega-merge — подтверждение с заводской стороны.

### Из этого следует важное для кнопки руля

DSC сидит на **PT-CAN** и читает `0x1D6` как чужое сообщение. Значит кадр
кнопок на PT-CAN доступен — либо изначально, либо через шлюз.

Это снимает главное сомнение по функции листания экранов: в захватах
DBC-mega-merge `0x1D6` есть только для K-CAN, PT-CAN-логов нет вовсе, и я
несколько раз оговаривался, что обучение кнопки может просто не найти
кандидата. Теперь есть заводское свидетельство, что найдёт. Окончательно
подтвердит `sniffer`.

---

## Что из этого реализовано

### Впуск — сделано

`lib/Diag` опрашивает DME раз в секунду запросом `30 0A 01` на `0x600` и
ждёт ответ на `0x608`. Температура выводится на первый экран в поле `IAT`.

Масштаб взят из SGBD и однозначен: «2 BYTE in −2048 bis 2048 Celsius,
Min −2047.9375» — это знаковое 16-битное с шагом 1/16 °C.

**Раскладка ответа выведена, а не подтверждена.** Из SGBD известно, что job
возвращает два двухбайтовых значения в порядке «сырое АЦП, затем
температура»; предполагается, что в кадре они лежат так же, сразу за эхом
идентификатора. Декодер отбрасывает значения вне −60…150 °C — при неверной
раскладке туда прилетит мусор, и лучше показать прочерк, чем выдумку.

Проверяется одним запуском: `sniffer` в третьей фазе шлёт тот же запрос и
печатает **сырой ответ**. Если байты 6–7, делённые на 16, дают правдоподобную
температуру — раскладка верна.

Это меняет посадку прошивки: `MCP_NORMAL` вместо `MCP_LISTENONLY`. Один
запрос раз в секунду, но устройство теперь **передаёт** в моторную шину.

### Баки — не сделано, и вот почему

Две независимые причины:

1. **KOMBI не на PT-CAN.** Приборка сидит на K-CAN, а адресация `0x600`-блока
   работает внутри PT-CAN. Достучаться можно через шлюз с колодки OBD, но это
   уже другая шина и другое подключение.
2. **Масштаб ответа неизвестен.** В комментариях SGBD у результатов
   `STAT_HEBELGEBER1_WERT` и остальных написано просто «Zahlenwert», единица
   возвращается отдельной строкой во время выполнения. Ни множителя, ни
   разрядности. То есть даже дотянувшись до KOMBI, пришлось бы подбирать
   масштаб опытным путём.

Причём есть путь проще: кадр `0x349` на K-CAN отдаёт **оба датчика сразу в
литрах**, декодер для него готов и покрыт тестами на реальных байтах —
`lib/KCan`. Опрос тут проигрывает вещанию по всем статьям.

**Поправка по масштабу.** Вторая причина снимается: скрытое меню приборки
показывает те же датчики в литрах (`06.00`) и в омах (`06.02`). Достаточно
сравнить показания меню с сырым ответом на `21 0A` при двух разных уровнях
топлива — множитель и смещение выводятся из этой пары.
См. [cluster-menu.md](cluster-menu.md). Бусовое ограничение остаётся:
приборка на K-CAN.

## Чего это стоит для устройства

Оба недостающих параметра достижимы, но **ценой перехода к передаче**.
Сейчас прошивка работает в `MCP_LISTENONLY` и физически не может отправить в
шину ни одного кадра — это была осознанная позиция.

Ещё одно следствие: приборка сидит на K-CAN, двигатель и коробка на PT-CAN, а
диагностические запросы через колодку OBD доходят до **всех** блоков через
шлюз. То есть для опроса нужна не та шина, к которой мы подключаемся сейчас.

Возможные конфигурации:

| Вариант | Что даёт | Чем платим |
|---|---|---|
| PT-CAN, только слушать (сейчас) | ОЖ, масло двигателя, ATF, напряжение | нет впуска и баков |
| OBD, только опрос | всё, включая баки и впуск | передача, медленнее, нет пассивности |
| PT-CAN слушать + опрашивать | всё | передача в моторную шину |

Транспорт под вопросом: заголовок `82 FF F1` — это формат K-line/KWP2000, а
на CAN тестер работает через ISO-TP на идентификаторе `0x6F1`. Сервис и
идентификатор от транспорта не зависят, а вот обрамление надо подтвердить
захватом — сканер это умеет, нужно только расширить диапазон печатаемых
ответов за пределы `0x7E8..0x7EF`.

---

## Чего это стоит для DBC-mega-merge

Прямо — немного: SGBD описывает диагностику, а не широковещание, и 275
пустых сообщений так не закрыть.

Косвенно — три вещи:

1. **Перекрёстная проверка.** Диапазоны и единицы из SGBD подтверждают или
   опровергают сигналы DBC. Пример выше с `TEMP_GRB` — ровно такой случай.
2. **Источник эталона.** Опрашивая job раз в секунду и одновременно записывая
   шину, получаем пары «известное значение — сырые байты». Это и есть
   недостающий вход для подбора масштаба и смещения неизвестных сигналов.
3. **Словарь имён.** A2L-имена вроде `tans` и немецкие названия дают
   осмысленный словарь для именования найденных сигналов вместо `Unknown_3`.

И отдельно — метод, который стоит прогнать по всему SP-Daten. Job'ы
`STATUS_F_CAN_*` documentируют широковещательные кадры **с заводской
стороны**: идентификатор запроса даёт CAN-ID, а список результатов — имена
полей. Это не корреляция и не гипотеза, а описание изготовителя.

### Сплошной поиск: результат

Прогнан по всем 379 файлам `.prg` (302 в `E89/ecu`, 77 в `BASE/ecu`)
инструментом `tools/scan_fcan.py`. **Отдача оказалась заметно меньше
ожидаемой** — я предполагал, что метод масштабируется, и ошибся.

```
уверенных совпадений: 13, уникальных кадров: 7
job'ов со словом Botschaft/Nachricht всего: 158
```

Из семи кадров реальными оказались пять, и **все они у одного семейства
блоков** — DSC_87 / DSC_89 / DXC_90, то есть один и тот же код в трёх
вариантах. Ни один другой блок E90 такой группы job'ов не имеет.

Остальные 158 упоминаний «Botschaft» — это диагностика состояния шины
(«ошибка сигнала CAN», «таймаут сообщения»), а не разбор кадров.

`ZGW_01` выглядел перспективно — шлюз с 14 упоминаниями и даже с job'ом
«вывести все сообщения выбранных шин» — но это шлюз F-серии: IP-конфигурация,
MOST, «приём CAN начиная с F10». К E90 не относится.

### Что это всё-таки дало DBC

Сравнение заводских имён полей с текущим DBC:

| Кадр | Завод | DBC | Итог |
|---|---|---|---|
| `0x1D6` | 7 полей, включая **`STAT_TASTER_HORN`** | 6 полей | завод даёт клаксон, которого в DBC нет |
| `0x2A6` | 4 поля | 2 поля | завод добавляет `WISCHERPOTI` и два значения |
| `0x194` | 3 поля | **11 сигналов** | DBC богаче: сообществу удалось больше |
| `0x118`, `0x140` | есть | — | требуют отдельного разбора |

**Существенное ограничение.** Заводские `RESULT` дают только *перечень* полей,
но не их положение в кадре: извлечение битов происходит в байткоде job'а.
То есть мы узнаём, что в `0x1D6` есть кнопка клаксона, но не узнаём, какой
это бит. Чтобы дойти до битов, надо интерпретировать разбирающий код job'а —
это отдельная и заметно более трудоёмкая работа.

### Остальные блоки: что ещё есть

| Блок | Полезное |
|---|---|
| `DSC_87` | `STATUS_RADGESCHWINDIGKEIT` `21 07` — скорости колёс по отдельности |
| `CAS` | `STATUS_HS_UBAT` `21 5D`, `STATUS_FZG_ZUSTAND` `22 10 15` — 14 байт состояния машины |
| `IHKA87` | `STATUS_SENSOREN_ANALOG_PORT` `30 13 01` — датчики климата, включая салонные |
| `FRM_87` | `STATUS_DIGITAL_INPUTS` `30 06 01` — входы освещения и переключателей |
| `JBBF87` | `STATUS_INTERNAL_VARIABLES` `30 06 01` — **122 результата** в одном запросе |

`IHKA87` любопытен тем, что климат уже меряет температуру салона — то есть
BME280, который вы отложили, частично дублирует штатный датчик.

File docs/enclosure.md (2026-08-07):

# Корпус под 3D-печать

Компоновочный эскиз. Две печатные детали, четыре винта M3, доступ к USB без
разборки.

| | |
|---|---|
| Габарит | 84 × 62 × 26 мм |
| Стенка | 2.0 мм, крышка 3.0 мм |
| Деталей | 2 печатных + 4 винта M3 |
| Задел | площадка под сенсорную кнопку |
| Материал | PETG или ASA, **не PLA** |
| Масштаб чертежей | 4 px/мм |
| Модель | [cad/enclosure.scad](../cad/enclosure.scad), OpenSCAD |

Форму продиктовало одно ограничение: MCP2515 (40 × 28 мм) и Nano (45 × 18 мм)
вместе занимают почти всю площадь дна, а дисплей 27 × 27 мм не помещается ни
на одну боковую стенку — она всего 26 мм высотой. Отсюда плоская шайба:
модули лежат на дне рядом, дисплей смотрит вверх через крышку.

---

## План дна

План дна корпуса

**Nano стоит длинной осью поперёк** не из эстетики: разъём USB-C у него на
короткой грани, и только в таком положении он выходит на заднюю стенку. Иначе
для каждой перепрошивки пришлось бы вскрывать корпус. Клеммник MCP2515 тоже
смотрит назад — туда же, куда уходит жгут.

---

## Разрез: почему хватает 26 мм

Разрез корпуса по высоте

Крышка 3.0 мм, а не 2.5: карман под дисплей глубиной 1.8 оставлял бы над
окном всего 0.7 мм — три слоя. При 3.0 остаётся 1.2, столько же, сколько под
лункой сенсора. На общую высоту это не влияет, свободного места внутри
хватает с запасом.

Высота набирается из 14 мм самого толстого модуля плюс дисплей под крышкой
плюс зазор. Дисплей утоплен в карман в крышке, а не висит на стойках — так он
не отъедает высоту.

Ключевая деталь: **провода к дисплею паять напрямую, без гребёнки**. Штыревой
разъём добавляет около 10 мм — ровно на них высота и не сходится.

---

## Крышка

Вид на крышку с окном и отверстиями

Слева — площадка под сенсорную кнопку. Подробности ниже, но главное видно
сразу: **отверстия там нет**. Пунктир на чертеже означает утоньшение стенки,
сплошной контур — сквозной проём.

Жёлтая полоска сверху окна — не украшение. У этой матрицы верхние 16 строк из
64 физически жёлтые, и вёрстка прошивки под это подогнана: там статус и
тревоги (см. `lib/Screen`). Окно должно попадать на активную зону так, чтобы
полоса оказалась сверху, иначе экран будет перевёрнут относительно замысла.

> **Промерьте дисплей перед моделированием.**
> Активная зона не по центру платы: стекло 27 × 27 мм, но светящиеся
> 21.7 × 10.9 мм смещены к одному краю. Замерьте штангенциркулем от края платы
> до края свечения по обеим осям и стройте окно от этого, а не от центра.

---

## Сенсорная кнопка TTP-223

В прошивке кнопка пока не задействована — задел на переключение экранов.
Механику под неё удобнее заложить сразу: переделывать напечатанную крышку
дороже, чем предусмотреть карман.

TTP-223 ёмкостной, и это меняет всю конструкцию узла: **отверстие ему не
нужно**, он срабатывает сквозь пластик. Наружу ничего не выходит, корпус
остаётся герметичным, а на крышке нет ни кнопки, ни щели, куда набьётся пыль.

Взамен появляются три требования.

**Стенку над сенсором надо утоньшить.** Крышка 3.0 мм — для ёмкостного
сенсора это заведомо много. Над пятном должно остаться
**1.2 мм**. Утоньшение делается снаружи лункой — см. следующий пункт, он
закрывает обе задачи разом.

**Модуль прижимается к крышке вплотную.** Воздушный зазор между пятном и
пластиком убивает чувствительность сильнее, чем лишний миллиметр материала.
Двусторонний скотч по краям платы или две печатные защёлки — но пятно должно
лежать на пластике.

**Место касания надо обозначить.** Снаружи ничего не выступает, и вслепую
кнопку не найти.

Решение — **лунка под палец с наружной стороны**: неглубокое круглое
углубление ⌀16 мм на 1.8 мм с плавными краями. Одна деталь делает сразу две
работы: даёт тактильную метку, в которую палец сам попадает и центрируется, и
одновременно **и есть то самое утоньшение** — 3.0 мм крышки минус 1.8 мм
лунки как раз оставляют нужные 1.2 мм. Отдельный карман изнутри при этом не
нужен, а внутренняя поверхность остаётся ровной, к ней проще прижать модуль.

Одна оговорка по геометрии. Сферическая лунка при печати крышкой вниз даёт по
кромке нависание около 70° — край поплывёт. Поэтому в модели делается не
сфера, а **усечённый конус с фасками 45°**: ⌀16 по верху, плоское дно ⌀12.4,
переход 1.8 мм. Пальцем разница не ощущается, а печатается без поддержек.

### Компоновка

Модуль встаёт на крышку слева от дисплея, над платой MCP2515. По разрезу
видно, что он свисает от крышки примерно на 2 мм, а до верха MCP2515 остаётся
**5.5 мм** — конфликта нет.

| | |
|---|---|
| Модуль TTP-223 | 15 × 11 × 2 мм (промерьте свой) |
| Остаётся материала | 1.2 мм |
| Лунка снаружи | ⌀16, глубина 1.8, фаски 45° |
| Зазор до MCP2515 | 5.5 мм |
| Ножка на Nano | D3, зарезервирована в `include/pins.h` |

### Если не сработает

Порядок действий, от простого к сложному:

1. Убедиться, что пятно действительно лежит на пластике без зазора.
2. Утоньшить до 1.0 мм. Ниже 0.8 идти не стоит — на 0.2 мм слое это две
   линии, крышка станет хлипкой в этом месте.
3. Наклеить на пятно кусочек медной или алюминиевой фольги 12 × 12 мм —
   расширенный электрод берёт ёмкость с большей площади. Приём известный и
   работает лучше, чем дальнейшее утоньшение.

Модуль по умолчанию сконфигурирован как «нажал–отпустил» с активным высоким
уровнем — именно это и ожидает `lib/Buttons`, где `digitalRead(...) == HIGH`
означает нажатие. Перемычки режимов на плате трогать не нужно.

---

## Порядок сборки

Разнесённая схема сборки

Дисплей ставится в карман изнутри **до** установки модулей: после того как
дно закрыто, до него уже не добраться.

---

## Спецификация

Габариты типовые — платы разных партий отличаются, свои стоит померить.
MCP2515 встречается и 40 × 28, и 51 × 28; Mini360 бывает 17 × 11 и 18 × 12.

| Компонент | Габарит, мм | Где стоит | Примечание |
|---|---|---|---|
| MCP2515 + TJA1050 | 40 × 28 × 14 | дно, слева сзади | клеммник CAN к задней стенке |
| Arduino Nano | 45 × 18 × 12 | дно, вдоль правой стенки | USB-C выходит на заднюю стенку |
| OLED 0.96″ | 27 × 27 × 4 | карман в крышке | провода паять напрямую |
| Mini360 | 17 × 11 × 4 | дно, слева спереди | настроить на 5 В до подключения |
| KY-006 | 19 × 15 × 9 | дно, по центру спереди | под решёткой в крышке |
| WS2812B | 10 × 10 × 3 | крышка, рядом с окном | под отверстием ⌀5 |
| TTP-223 | 15 × 11 × 2 | крышка, слева от окна | без отверстия, под лункой ⌀16 |

---

## Модель

Параметрическая модель — [cad/enclosure.scad](../cad/enclosure.scad). Исходник
текстовый: правится в любом редакторе, все размеры вынесены в параметры
наверху файла.

```bash
brew install --cask openscad          # если ещё не стоит

openscad -D 'part="shell"' -o shell.stl cad/enclosure.scad
openscad -D 'part="base"'  -o base.stl  cad/enclosure.scad
```

Без аргументов файл открывается в GUI и показывает обе детали рядом.

Промерьте свои платы и поправьте параметры перед печатью. Критичнее всего
`win_dx` / `win_dy` — смещение окна относительно центра платы дисплея, и
`usb_x` / `usb_z0` — положение разъёма, которое у клонов Nano гуляет.

**Печатайте крышку первой и отдельно.** Она несёт все ответственные размеры:
окно, карман, лунку, вырез USB. Проверить их на одной детали за час дешевле,
чем обнаружить промах после печати всего корпуса.

---

## Печать

### PLA здесь не годится

Торпедо под солнцем летом уходит за 70 °C, а PLA размягчается около 55–60.
Корпус поведёт, и он перестанет держать дисплей в кармане. Печатайте **PETG** —
достаточно и просто в работе, — либо **ASA**, если корпус будет на прямом
солнце и хочется запаса по УФ.

### Ориентация на столе

Корпус кладётся **крышкой вниз**. Тогда лицевая поверхность выходит гладкой
прямо со стола, окно дисплея печатается без поддержек, стенки идут
вертикально. Донная пластина печатается плашмя.

Единственное место, требующее внимания, — отверстие кабельного ввода в
вертикальной задней стенке. Круглое ⌀7 нависнет в верхней точке; сделайте его
каплевидным, сведённым сверху под 45° — тогда поддержки не нужны и там.

### Параметры

| Параметр | Значение | Почему |
|---|---|---|
| Слой | 0.2 мм | компромисс скорости и вида лицевой грани |
| Периметры | 3 | 2 мм стенка — ровно три прохода соплом 0.4 |
| Заполнение | 25 % | нагрузок нет, важнее жёсткость крышки |
| Поддержки | нет | при печати крышкой вниз не нужны |
| Крепёж | M3 × 10 самонарез | отверстие в бобышке ⌀2.6, бобышка ⌀6 |

### Что ещё предусмотреть

- **Разгрузка жгута.** Стойка под стяжку внутри, сразу за кабельным вводом.
  Без неё рывок за провод вырывает клеммник из MCP2515.
- **Вентиляция.** Несколько прорезей в донной пластине под Mini360 — он
  единственный, что заметно греется.
- **Крепление.** Площадка под 3M VHB на дне либо паз под клипсу дефлектора.
  При печати дна плашмя ровная нижняя грань получается сама.
- **Рассеиватель.** В отверстие ⌀5 над светодиодом — капля прозрачного
  термоклея. Иначе видна точка кристалла вместо ровного свечения.
- **Лунка сенсора.** Печатается заодно с крышкой; фаски 45° по кромке
  обязательны, иначе при печати крышкой вниз край поплывёт.
- **Допуск на USB.** У клонов Nano разъём смещён от партии к партии. Заложите
  вырез с запасом 1 мм по сторонам либо промерьте свою плату до печати.

### Угол обзора

Корпус нарисован плоским. Если поставить его на торпедо, экран будет смотреть
в потолок. Наклон практичнее печатать отдельным клином под низ, чем встраивать
в корпус: угол на разных панелях нужен разный, а клин переделать — двадцать
минут печати против переделки всей модели.

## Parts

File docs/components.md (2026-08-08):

# Компоненты и работа с ними

Справка по закупленным модулям: назначение, подводные камни, статус в
проекте. Полная распайка — в [wiring.md](wiring.md), корпус — в
[enclosure.md](enclosure.md).

Машина: **BMW E90 318i, 2011 (LCI), N46B20 бензин, АКПП ZF 6HP19.**

| Компонент | Кол-во | Ножка | В сборке |
|---|---|---|---|
| Arduino Nano V3.0 TYPE-C, CH340 | 1 | — | да |
| MCP2515 + TJA1050, CAN | 1 | D10 CS, D2 INT, SPI | да |
| OLED 0.96″ 128×64 I2C, жёлто-синий | 1 | A4 SDA, A5 SCL | да |
| Mini360, DC-DC | 2 | — | используется 1 |
| WS2812B, адресный светодиод | 5 | D6 | используется 1 |
| KY-006, пассивный зуммер | 1 | D9 | да |
| TTP-223, сенсорная кнопка | 4 | D3 (резерв) | нет, задел |
| BME280 | 0 | A4/A5 | не куплен |
| PLS-40, DuPont | — | — | межблочка |

---

## Arduino Nano V3.0 TYPE-C, CH340

**Загрузчик новый.** Плата с USB-C и CH340 — это почти всегда Optiboot,
отсюда `board = nanoatmega328new` в `platformio.ini`. Со старым
`nanoatmega328` прошивка не зальётся: не совпадёт скорость загрузчика.

Это же делает безопасным сторожевой таймер: Optiboot сбрасывает флаг `WDRF`
при старте. Со старым загрузчиком первое срабатывание `wdt_enable()` загоняло
плату в бесконечную перезагрузку, и спасал только программатор.

**Драйвер CH340.** Если порт не появляется в `ls /dev/cu.*`:

```bash
brew install --cask wch-ch34x-usb-serial-driver
```

**Питание.** Готовые 5 В подаются на вывод `5V`, **не на `VIN`**: `VIN` идёт
через встроенный стабилизатор, рассчитанный на 7–12 В, и от пяти вольт на
выходе получится три с половиной.

**USB и внешнее питание одновременно не подключать.** На клонах линия
USB-питания и вывод `5V` связаны без развязки, два источника начинают
бороться.

**Память — главный ограничитель проекта.** 32 КБ флеша (30720 доступно) и
2 КБ RAM. Текущее состояние: флеш 76 %, RAM 72 %. Замеренная стоимость:
FastLED 3018 байт, печать `float` 758 байт, крупный шрифт 402 байта.
Расширить память внешним модулем **нельзя** — ATmega328P гарвардский и
выполняет код только из внутренней флеш-памяти.

---

## MCP2515 + TJA1050

**Проверьте кварц.** На банке рядом с чипом написано `8.000` или `16.000`.
В `platformio.ini` стоит `-D MCP2515_CRYSTAL_MHZ=8`. При неверном значении
тайминги бит-рейта считаются неправильно, и шина либо не поднимется, либо
будет сыпать мусором. Причина номер один, по которой «ничего не работает».

**Терминатор 120 Ом надо выпаять.** Плата приходит с резистором между CAN H
и CAN L. Он нужен при построении шины с нуля и вреден при подключении к
готовой: у машины уже есть два своих терминатора, суммарно 60 Ом, и третий
опускает сопротивление до 40. Симптом коварный — работает «через раз».
Проверяется мультиметром на обесточенном модуле.

**Питание 5 В.** Трансиверу TJA1050 нужны именно пять вольт.

**Библиотека хочет `unsigned long`.** `readMsgBuf(INT32U *id, ...)`, где
`INT32U` это `unsigned long`. На AVR совпадает с `uint32_t`, поэтому
собирается, но IntelliSense ругается, а на STM32 и ESP32 это станет
настоящей ошибкой. Во всех вызовах переменная объявлена как `unsigned long`.

**Фильтры обязательны.** PT-CAN даёт 1500–2000 кадров в секунду, у MCP2515
два приёмных буфера. Без фильтров кадры теряются **молча**. Настроены маски
`0x7FF` и все шесть фильтров; занято четыре, два дублируют последний, потому
что пустой фильтр пропускает всё подряд.

---

## OLED 0.96″ 128×64, жёлто-синий

Контроллер **SSD1306**, адрес `0x3C`. Библиотека U8g2 в **page-режиме**:
буфер 128 байт вместо 1024, полнокадровый на Nano не помещается.

**Двухцветность физическая.** Верхние 16 строк из 64 всегда жёлтые, ниже
синие, границу не подвинуть. Вёрстка это учитывает: жёлтая полоса — статус и
тревоги, данные целиком ниже строки 16. Крупный шрифт без учёта границы
разрезается пополам и выглядит как брак.

**Активная зона смещена.** Стекло 27 × 27 мм, светящиеся 21.7 × 10.9 мм — не
по центру платы. Перед моделированием корпуса промерьте штангенциркулем от
края платы до края свечения по обеим осям.

**Провода паять напрямую, без гребёнки.** Штыревой разъём добавляет около
10 мм высоты, которых в корпусе нет.

**В наборах `logisoso*_tn` только цифры.** Точки и минуса там может не
оказаться, поэтому крупно рисуется целая часть, а хвост (`C`, `.1V`) —
мелким шрифтом; минус рисуется прямоугольником вручную.

---

## Mini360

**Настраивать до подключения нагрузки.** Подать 12 В, выставить
подстроечником 5.0 В по мультиметру, и только потом подключать Arduino. При
обратном порядке на выходе может оказаться входное напряжение, и Nano вместе
с дисплеем уходит в утиль за секунду.

Предел 1.8 А при нашем потреблении ~60 мА — запас многократный. Из двух
модулей используется один, второй в запасе.

---

## WS2812B

**Платите за библиотеку, а не за диоды.** FastLED стоит 3018 байт флеша
независимо от количества; каждый диод — 3 байта RAM. Разница между одним и
пятью — двенадцать байт. Для единственного светодиода 3 КБ расточительно;
альтернатива — ручной бит-бэнг примерно на 100 байт, но там критичные
тайминги.

**`show()` нельзя дёргать каждый проход `loop()`.** На AVR он запрещает
прерывания на всё время передачи. Последствия неочевидные: отстаёт `millis()`,
на котором висит вся логика протухания данных, ломается `tone()`, страдает
приём по I2C. Вызывается только при смене состояния.

Подключается вход `DIN`, не `DOUT`. В отверстие ⌀5 над диодом стоит капнуть
прозрачного термоклея, иначе видна точка кристалла.

---

## KY-006

Пассивный: питание не нужно, звук получается прямо из меандра на сигнальном
выводе. `S` → `D9`, `−` → `GND`, средний вывод на большинстве плат не
подключён.

`tone()` на AVR всегда занимает **Timer2** независимо от выбранной ноги.
С `FastLED.show()`, который кратко запрещает прерывания, на одном диоде
конфликт незаметен, но если услышите щелчки в писке — причина здесь.

---

## TTP-223 — задел, в прошивке не используется

**Ёмкостной: отверстие не нужно**, срабатывает сквозь пластик. В корпусе
предусмотрена лунка под палец снаружи ⌀16 глубиной 1.8 мм — она же и
утоньшение, под пальцем остаётся 1.2 мм.

Три требования: стенку утоньшить, модуль прижать к крышке **без воздушного
зазора**, место касания обозначить. Если не сработает — сначала проверить
прижим, потом утоньшить до 1.0 мм, потом наклеить на пятно фольгу 12 × 12 мм.

По умолчанию работает как «нажал–отпустил» с активным высоким уровнем —
именно это ожидает `lib/Buttons`. Перемычки режимов трогать не нужно.

Переключение экранов сейчас сделано **кнопкой на руле** через CAN, так что
TTP-223 остаётся запасным вариантом.

---

## BME280 — не куплен

Планировался под климат в салоне. Учтите: **IHKA уже меряет температуру
салона** и отдаёт её диагностическим запросом `30 13 01`
(`STATUS_SENSOREN_ANALOG_PORT`). Так что модуль частично дублирует штатный
датчик — возможно, покупать и не понадобится.

Садится на ту же шину I2C, что и дисплей, адрес `0x76` или `0x77`.
Отдельных ног не требует.

---

## Быстрые команды

```bash
export PATH="$PATH:$HOME/.platformio/penv/bin"

pio test -e native          # тесты на Mac, без железа
pio run                     # сборка прошивки
pio run -t upload           # прошивка
pio run -e sniffer -t upload && pio device monitor   # разведка шины
./sim/build.sh              # картинка экранов без железа
```

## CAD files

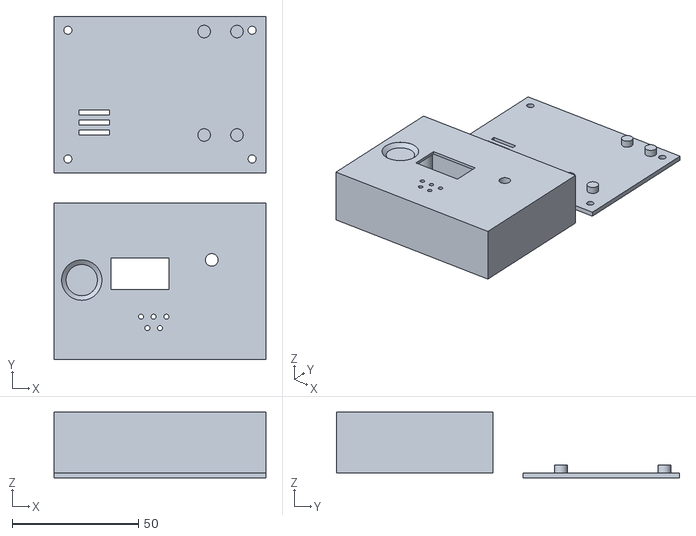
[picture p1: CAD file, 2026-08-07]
output2.stl
84.0 x 136.0 x 26.0

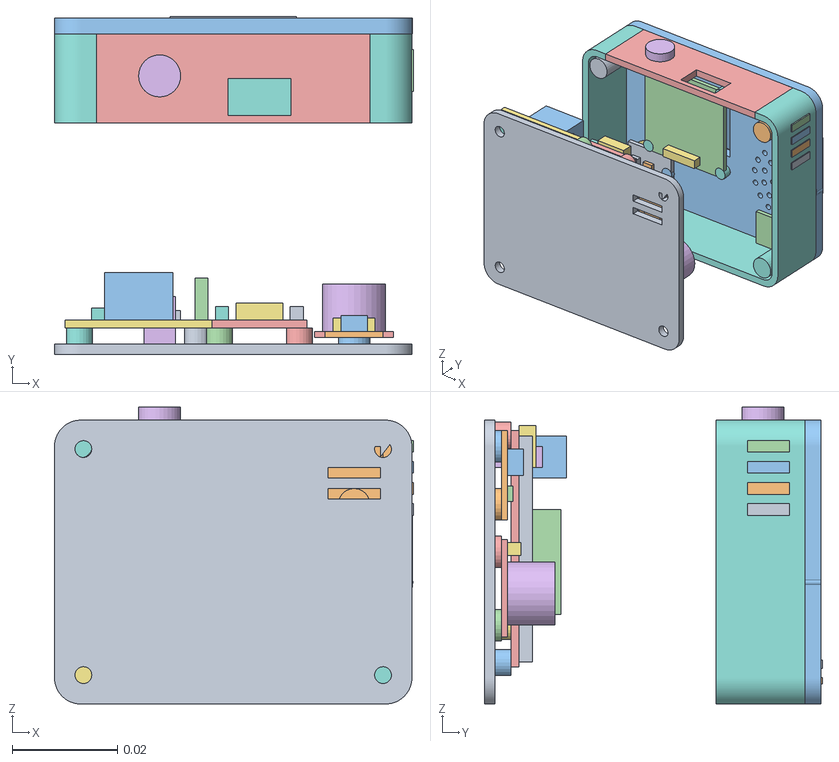
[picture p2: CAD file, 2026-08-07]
enclosure-layout.obj
0.0683 x 0.0643 x 0.0565
base_plate
standoff_nano_0
standoff_nano_1
standoff_nano_2
standoff_nano_3
standoff_can_0
standoff_can_1
standoff_can_2
standoff_can_3
pad_mini360_a
pad_mini360_b
pad_buzzer_a
pad_buzzer_b
strain_relief_post
can_pcb
can_mcp2515
can_tja1050
can_crystal
can_terminal
can_header
nano_pcb
nano_mcu
nano_usb_c
nano_header_l
nano_header_r
mini360_pcb
mini360_inductor
mini360_ic
buzzer_pcb
buzzer_body
buzzer_header
shell_walls
vent_slot_r_0
vent_slot_r_1
vent_slot_r_2
vent_slot_r_3
shell_rear_panel
cable_gland
boss_lf
boss_rf
boss_lb
boss_rb
lid
touch_dimple
touch_dimple_floor
touch_dimple_wall
touch_dimple_underside
label_touch
label_bmw_e90
label_can_bus
display_bezel
oled_pcb
oled_glass
oled_pixels
oled_header
oled_clamp
ttp223_pcb
ttp223_ic
ttp223_clamp
ws2812_pcb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

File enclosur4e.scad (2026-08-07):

// Корпус бортового дисплея BMW E90 / CAN — параметрическая модель для печати.
// Только печатаемые детали: корпус (крышка со стенками) и донная пластина.
//
// Экспорт STL для OrcaSlicer:
//   openscad -D 'part="shell"' -o shell.stl enclosure.scad
//   openscad -D 'part="base"'  -o base.stl  enclosure.scad
//
// Печать: обе детали лицом вниз (крышка — наружной поверхностью на стол),
// PETG или ASA, поддержки не нужны. Гравировка, лунка, воронка окна и
// каплевидный ввод рассчитаны именно под эту ориентацию.
//
// СИСТЕМА КООРДИНАТ
//   X — ширина, 0 слева
//   Y — глубина, 0 спереди (к водителю), box_d сзади (разъёмы)
//   Z — высота, 0 — плоскость стыка корпуса и донной пластины
//
// ВАЖНО: габариты модулей типовые. Промерьте свои платы штангенциркулем.
// Особенно: активная зона OLED смещена от центра платы, и вырез под USB —
// у клонов Nano разъём гуляет от партии к партии.

part = "both";   // "shell" | "base" | "both"

$fn = 72;
eps = 0.01;
over = 0.5;      // выход вырезов за поверхность: совпадающие грани дают артефакты в слайсере

/* ================= ОСНОВНЫЕ РАЗМЕРЫ ================= */

box_w  = 72;
box_d  = 54;
box_h  = 22;     // полная высота вместе с донной пластиной
wall   = 2.0;
lid_t  = 3.0;
base_t = 2.0;
corner = 5.0;    // радиус вертикальных углов

shell_h  = box_h - base_t;      // 20
cavity_h = shell_h - lid_t;     // 17

/* ================= КРЕПЁЖ ================= */

boss_od    = 6.0;
boss_pilot = 2.6;    // под самонарез M3
boss_inset = 5.5;
base_clear = 3.2;

boss_pos = [
  [boss_inset,         boss_inset],
  [box_w - boss_inset, boss_inset],
  [boss_inset,         box_d - boss_inset],
  [box_w - boss_inset, box_d - boss_inset]
];

/* ================= ПЛАТЫ (справочно, для проверки коллизий) =========
   Бобышки крепежа занимают круги d=6 в углах (5.5,5.5) (66.5,5.5)
   (5.5,48.5) (66.5,48.5) на всю высоту полости — платы их обходят.

   Nano      18 x 45, x  9..27, y  4..49, USB к задней стенке
   MCP2515   28 x 40, x 27..55, y  6..46
   Mini360   11 x 15, x 55..66, y 30..45
   KY-006    15 x 18.5, x 52..67, y 10..28.5
   OLED      27.5 x 27.5, к крышке, центр (34, 28)
   TTP223    15 x 11, к крышке, центр (11, 16) — x 3.5..18.5, y 10.5..21.5
   WS2812B   10 x 10, к крышке, центр (45, 8)
   ==================================================================== */

nano_holes = [[10.4, 4.9], [25.6, 4.9], [10.4, 48.1], [25.6, 48.1]];
can_holes  = [[29.75, 8.75], [52.25, 8.75], [29.75, 43.25], [52.25, 43.25]];
pcb_pad_h  = 3.0;    // высота стоек под платы
pcb_pad_d  = 5.0;

// клеевые площадки под модули без отверстий
glue_pads = [[60.5, 32.5], [60.5, 42.5],  // Mini360
             [59.5, 13],  [59.5, 25.5]];  // KY-006

/* ================= ДИСПЛЕЙ ================= */

oled_cx = 34;
oled_cy = 28;
oled_pcb    = 27.6;   // сторона платы плюс зазор
oled_pocket = 1.4;    // карман в крышке под толщину платы

// Окно-воронка: снаружи шире, внутри по активной зоне. Скос ~40° убирает
// толщину крышки из поля зрения и печатается крышкой вниз без поддержек.
win_w  = 23.0;        // внутри, активная зона 21.7 x 10.9 плюс зазор
win_h  = 12.5;
win_flare = 2.5;      // расширение на сторону к наружной поверхности
win_dy = 1.0;         // активная зона смещена — ПРОМЕРИТЬ

// прижимные лапки, держат плату OLED в кармане
clamp_d = 3.4;
clamp_h = 2.4;

/* ================= СЕНСОРНАЯ КНОПКА ================= */

// Лунка под палец СНАРУЖИ, она же утоньшение для TTP-223: отверстия нет,
// под пальцем остаётся lid_t - dimple_depth = 1.2 мм. Геометрия —
// усечённый конус с фаской 45°, а не сфера: сферическая лунка при печати
// крышкой вниз даёт по кромке нависание около 70° и край плывёт.
dimple_d     = 15.0;
dimple_depth = 1.8;
// Центр смещён влево: лунка X 3.5..18.5, карман OLED от X 20.2 — зазор 1.7.
dimple_x     = 11;     // = центр TTP223
dimple_y     = 16;     // выше бобышки (Y<=8.5): лунка Y 8.5..23.5

touch_text   = "TOUCH";
touch_size   = 3.0;
engrave_d    = 0.4;   // глубина гравировки

/* ================= НАДПИСИ НА КРЫШКЕ ================= */

label_1 = "BMW E90";
label_2 = "CAN BUS";
// Полоса между лункой (правый край X=18.5) и отверстием LED (левый край X=42.5).
// BMW E90 — X 23.3..40.7, CAN BUS — X 25..39.
label_x = 32;
label_1_y = 12.5;
label_2_y = 6.0;
label_1_size = 4.0;
label_2_size = 3.2;

/* ================= СВЕТОДИОД И ЗУММЕР ================= */

led_d = 5.0;
led_x = 45;
led_y = 8;

// Решётка: три концентрические дуги отверстий вместо россыпи точек.
buzz_x = 61.0;
buzz_y = 20;
buzz_hole_d = 1.6;
buzz_rings  = [[3.4, 6], [6.1, 9], [8.8, 12]];
buzz_span   = 130;    // угловой раствор веера, градусов
// габарит дуг: x 61 +/- 8.0 = 53.0..69.0, y 11.2..20 — внутри стенок

/* ================= ВЫВОДЫ НАРУЖУ ================= */

gland_d = 7.0;        // кабельный ввод, задняя стенка
gland_x = 45;
gland_z = 9;

usb_w  = 12;          // вырез под USB-C, задняя стенка
usb_h  = 7;
usb_x  = 18;
usb_z0 = 3.5;

/* ================= РАЗГРУЗКА ЖГУТА ================= */

sr_x = 42;
sr_y = 46;
sr_w = 6;
sr_d = 4;
sr_h = 9;

/* ================= ВЕНТИЛЯЦИЯ ================= */

// Сквозная тяга через узел Mini360: приток через дно, выброс через правую
// стенку. Щели только в дне не работают — воздуху некуда уходить.
vent_slot_w = 2.2;    // прорези в правой стенке
vent_slot_h = 8;
vent_slot_z = 6;
vent_wall_ys = [32, 36, 40, 44];

vent_floor_w  = 10;   // щели в дне
vent_floor_h  = 2;
vent_floor_x  = 55;   // щели между клеевыми площадками Mini360
vent_floor_ys = [36.5, 38.5];

/* =====================================================
   ВСПОМОГАТЕЛЬНОЕ
   ===================================================== */

// Скруглённая по вертикальным углам плита.
module rounded_slab(w, d, h, r) {
  hull() for (x = [r, w - r], y = [r, d - r])
    translate([x, y, 0]) cylinder(h = h, r = r);
}

// Каплевидное отверстие: круг с надстройкой под 45° сверху. Обычное круглое
// отверстие в вертикальной стенке нависает в верхней точке и требует
// поддержек; каплевидное печатается само.
module teardrop_2d(r) {
  union() {
    circle(r = r);
    polygon(points = [
      [-r * 0.7071, r * 0.7071],
      [ r * 0.7071, r * 0.7071],
      [ 0,          r * 1.4142]
    ]);
  }
}

module boss(h) {
  difference() {
    cylinder(h = h, d = boss_od);
    translate([0, 0, -eps]) cylinder(h = h + 2 * eps, d = boss_pilot);
  }
}

module strain_relief() {
  difference() {
    translate([sr_x, sr_y, 0]) cube([sr_w, sr_d, sr_h]);
    translate([sr_x + sr_w / 2 - 1.5, sr_y - 1, 3.5])
      cube([3, sr_d + 2, 4]);
  }
}

// Гравировка на наружной поверхности крышки: текст утоплен на engrave_d.
// Печатается крышкой вниз идеально; накладной текст лёг бы в стол.
module lid_engrave(txt, size, x, y, z_top) {
  translate([x, y, z_top - engrave_d])
    linear_extrude(height = engrave_d + over)
      text(txt, size = size, halign = "center", valign = "center",
           font = "DejaVu Sans:style=Bold", $fn = 32);
}

/* =====================================================
   КОРПУС: крышка со стенками, снизу открыт
   ===================================================== */

module shell() {
  union() {
    difference() {
      rounded_slab(box_w, box_d, shell_h, corner);

      // --- внутренняя полость, открытая вниз ---
      translate([wall, wall, -eps])
        rounded_slab(box_w - 2 * wall, box_d - 2 * wall,
                     cavity_h + eps, max(corner - wall, 0.5));

      // --- карман под плату дисплея ---
      translate([oled_cx - oled_pcb / 2, oled_cy - oled_pcb / 2, cavity_h - eps])
        cube([oled_pcb, oled_pcb, oled_pocket + eps]);

      // --- окно дисплея: воронка, наружу расширяется ---
      translate([oled_cx, oled_cy + win_dy, cavity_h - over])
        linear_extrude(height = lid_t + 2 * over, scale = [
          (win_w + 2 * win_flare) / win_w,
          (win_h + 2 * win_flare) / win_h
        ])
          square([win_w, win_h], center = true);

      // --- отверстие под WS2812B ---
      translate([led_x, led_y, cavity_h - over])
        cylinder(h = lid_t + 2 * over, d = led_d);

      // --- решётка зуммера: концентрические дуги ---
      for (ring = buzz_rings)
        for (i = [0 : ring[1] - 1]) {
          a = -buzz_span / 2 + buzz_span * i / (ring[1] - 1);
          translate([buzz_x + sin(a) * ring[0],
                     buzz_y - cos(a) * ring[0],
                     cavity_h - over])
            cylinder(h = lid_t + 2 * over, d = buzz_hole_d);
        }

      // --- лунка под палец, снаружи ---
      translate([dimple_x, dimple_y, shell_h - dimple_depth])
        cylinder(h = dimple_depth + over,
                 d1 = dimple_d - 2 * dimple_depth,   // фаска 45°
                 d2 = dimple_d + 2 * over);

      // --- гравировка ---
      lid_engrave(touch_text, touch_size, dimple_x, dimple_y,
                  shell_h - dimple_depth);
      lid_engrave(label_1, label_1_size, label_x, label_1_y, shell_h);
      lid_engrave(label_2, label_2_size, label_x, label_2_y, shell_h);
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

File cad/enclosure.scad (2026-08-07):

// Корпус бортового дисплея BMW E90 — параметрическая модель для печати.
//
// Рендер и экспорт:
//   openscad enclosure.scad                              — открыть в GUI
//   openscad -D 'part="shell"' -o shell.stl enclosure.scad
//   openscad -D 'part="base"'  -o base.stl  enclosure.scad
//
// Печать: обе детали лицом вниз, PETG или ASA, поддержки не нужны.
// Подробности — в docs/enclosure.md, распайка — в docs/wiring.md.
//
// СИСТЕМА КООРДИНАТ
//   X — ширина, 0 слева
//   Y — глубина, 0 спереди (к водителю), box_d сзади (к стеклу)
//   Z — высота, 0 — плоскость стыка корпуса и донной пластины
//
// ВАЖНО: габариты модулей типовые. Промерьте свои платы штангенциркулем и
// поправьте параметры — особенно активную зону дисплея, она смещена от
// центра платы, и вырез под USB, у клонов Nano разъём гуляет от партии.

part = "both";   // "shell" | "base" | "both"

$fn = 64;
eps = 0.01;

/* ================= ОСНОВНЫЕ РАЗМЕРЫ ================= */

box_w   = 84;    // ширина
box_d   = 62;    // глубина
box_h   = 26;    // полная высота вместе с донной пластиной
wall    = 2.0;   // боковые стенки
lid_t   = 3.0;   // крышка
base_t  = 2.0;   // донная пластина

shell_h  = box_h - base_t;      // 24 — высота корпуса без дна
cavity_h = shell_h - lid_t;     // 21 — свободная высота внутри

/* ================= КРЕПЁЖ ================= */

boss_od    = 6.0;    // наружный диаметр бобышки
boss_pilot = 2.6;    // отверстие под самонарез M3
boss_inset = 5.5;    // от края корпуса до центра бобышки
base_clear = 3.2;    // отверстие в донной пластине под M3

boss_pos = [
  [boss_inset,         boss_inset],
  [box_w - boss_inset, boss_inset],
  [boss_inset,         box_d - boss_inset],
  [box_w - boss_inset, box_d - boss_inset]
];

/* ================= ДИСПЛЕЙ ================= */

// Плата OLED утоплена в карман в крышке, окно прорезано под активную зону.
// Над карманом остаётся lid_t - oled_pocket = 1.2 мм.
oled_pcb    = 27.6;   // сторона платы плюс зазор
oled_pocket = 1.8;
oled_cx     = 34;
oled_cy     = 33;

win_w  = 23.0;        // окно чуть больше активной зоны 21.7 x 10.9
win_h  = 12.5;
win_dx = 0;           // смещение окна относительно центра ПЛАТЫ
win_dy = 1.0;         // активная зона смещена — ОБЯЗАТЕЛЬНО ПРОМЕРИТЬ

/* ================= СВЕТОДИОД И ЗУММЕР ================= */

led_d = 5.0;
led_x = 62.5;
led_y = 39.5;

// Решётка ровно над зуммером, который лежит на дне в зоне x 30..49, y 9.5..24.5
buzz_hole_d = 2.0;
buzz_x = 39.5;
buzz_y = 17.0;

/* ================= СЕНСОРНАЯ КНОПКА ================= */

// Лунка под палец СНАРУЖИ. Она же и есть утоньшение: отверстия нет,
// под пальцем остаётся lid_t - dimple_depth = 1.2 мм.
// Геометрия — усечённый конус с фасками 45°, а не сфера: сферическая лунка
// при печати крышкой вниз даёт по кромке нависание около 70° и край плывёт.
dimple_d     = 16.0;
dimple_depth = 1.8;
dimple_x     = 11;
dimple_y     = 31.5;

/* ================= ВЫВОДЫ НАРУЖУ ================= */

// Ввод стоит в промежутке между MCP2515 и Nano — там же внутри стойка
// разгрузки, и жгуту есть куда лечь.
gland_d = 7.0;
gland_x = 53;
gland_z = 12;

usb_w  = 12;          // вырез под USB-C
usb_h  = 7;
usb_x  = 66.5;        // центр по X
usb_z0 = 3.5;         // от плоскости дна

/* ================= РАЗГРУЗКА ЖГУТА ================= */

sr_x = 50;   // стойка со сквозным пазом под стяжку
sr_y = 52;
sr_w = 6;
sr_d = 4;
sr_h = 8;

/* ================= ПОДСТАВКИ ПОД NANO ================= */

// Плата поднята, чтобы разъём USB-C попал в вырез в задней стенке.
nano_pad_h = 3.0;
nano_pad_d = 5.0;
nano_pads = [[59.5, 15], [72.5, 15], [59.5, 56], [72.5, 56]];

/* ================= ВЕНТИЛЯЦИЯ ================= */

// Прорези в дне под Mini360 (x 7.5..24.5, y 13.5..24.5) — единственный узел,
// который заметно греется.
vent_w  = 12;
vent_h  = 2;
vent_x  = 10;
vent_ys = [15, 19, 23];

/* =====================================================
   ВСПОМОГАТЕЛЬНОЕ
   ===================================================== */

// Каплевидное отверстие: круг с надстройкой под 45° сверху. Обычное круглое
// отверстие в вертикальной стенке нависает в верхней точке и требует
// поддержек; каплевидное печатается само.
module teardrop_2d(r) {
  union() {
    circle(r = r);
    polygon(points = [
      [-r * 0.7071, r * 0.7071],
      [ r * 0.7071, r * 0.7071],
      [ 0,          r * 1.4142]
    ]);
  }
}

module boss(h) {
  difference() {
    cylinder(h = h, d = boss_od);
    translate([0, 0, -eps]) cylinder(h = h + 2 * eps, d = boss_pilot);
  }
}

module strain_relief() {
  difference() {
    translate([sr_x, sr_y, 0]) cube([sr_w, sr_d, sr_h]);
    // сквозной паз под стяжку
    translate([sr_x + sr_w / 2 - 1.5, sr_y - 1, 3])
      cube([3, sr_d + 2, 4]);
  }
}

/* =====================================================
   КОРПУС: крышка со стенками, снизу открыт
   ===================================================== */

module shell() {
  // Бобышки и стойка добавляются ПОСЛЕ выборки полости — иначе полость
  // срезала бы их подчистую.
  union() {
    difference() {
      cube([box_w, box_d, shell_h]);

      // внутренняя полость, открытая вниз
      translate([wall, wall, -eps])
        cube([box_w - 2 * wall, box_d - 2 * wall, cavity_h + eps]);

      // --- карман под плату дисплея, снизу ---
      translate([oled_cx - oled_pcb / 2, oled_cy - oled_pcb / 2, cavity_h - eps])
        cube([oled_pcb, oled_pcb, oled_pocket + eps]);

      // --- окно дисплея, насквозь ---
      translate([oled_cx + win_dx - win_w / 2,
                 oled_cy + win_dy - win_h / 2,
                 cavity_h - eps])
        cube([win_w, win_h, lid_t + 2 * eps]);

      // --- отверстие под светодиод ---
      translate([led_x, led_y, cavity_h - eps])
        cylinder(h = lid_t + 2 * eps, d = led_d);

      // --- решётка зуммера ---
      for (o = [[-5, 0], [0, 0], [5, 0], [-2.5, -4.5], [2.5, -4.5]])
        translate([buzz_x + o[0], buzz_y + o[1], cavity_h - eps])
          cylinder(h = lid_t + 2 * eps, d = buzz_hole_d);

      // --- лунка под палец, снаружи ---
      translate([dimple_x, dimple_y, shell_h - dimple_depth])
        cylinder(h = dimple_depth,
                 d1 = dimple_d - 2 * dimple_depth,   // фаска 45°
                 d2 = dimple_d);
      translate([dimple_x, dimple_y, shell_h - eps])
        cylinder(h = 1, d = dimple_d);

      // --- кабельный ввод в задней стенке ---
      translate([gland_x, box_d + 2, gland_z])
        rotate([90, 0, 0])
          linear_extrude(height = wall + 4)
            teardrop_2d(gland_d / 2);

      // --- вырез под USB-C в задней стенке ---
      translate([usb_x - usb_w / 2, box_d - wall - 1, usb_z0])
        cube([usb_w, wall + 2, usb_h]);
    }

    for (p = boss_pos)
      translate([p[0], p[1], 0]) boss(cavity_h);

    strain_relief();
  }
}

/* =====================================================
   ДОННАЯ ПЛАСТИНА
   ===================================================== */

module base_plate() {
  difference() {
    union() {
      translate([0, 0, -base_t])
        cube([box_w, box_d, base_t]);

      // подставки под Nano поднимают плату к вырезу USB
      for (p = nano_pads)
        translate([p[0], p[1], 0])
          cylinder(h = nano_pad_h, d = nano_pad_d);
    }

    for (p = boss_pos)
      translate([p[0], p[1], -base_t - eps])
        cylinder(h = base_t + 2 * eps, d = base_clear);

    for (y = vent_ys)
      translate([vent_x, y, -base_t - eps])
        cube([vent_w, vent_h, base_t + 2 * eps]);
  }
}

/* =====================================================
   ВЫВОД
   ===================================================== */

if (part == "shell") shell();
else if (part == "base") base_plate();
else {
  shell();
  translate([0, box_d + 12, 0]) base_plate();
}

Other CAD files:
output4.stl
output3.stl
enclosure.scad
enclosure3.scad

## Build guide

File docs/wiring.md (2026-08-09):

# Схема подключения и сборка

Итоговая распайка устройства: дисплей, CAN, зуммер, светодиод и сенсорная
кнопка. Здесь же — чем отличается отладка на столе от штатной установки.

---

## Земля одна на всё устройство

Короткий ответ на частый вопрос: **в устройстве ровно одна земля**. GND
Arduino, GND модуля MCP2515, GND дисплея, зуммера, светодиода и масса кузова
автомобиля — это всё **один и тот же провод**. Отдельной «земли CAN» не
существует.

**CAN H и CAN L землёй не являются.** Это дифференциальная пара: приёмник
смотрит на разность напряжений между ними, а не на их уровень относительно
массы. Соединять их с землёй нельзя ни при каких обстоятельствах.

Тогда зачем масса вообще нужна, если сигнал дифференциальный? Затем, что
трансиверу TJA1050 нужна собственная точка отсчёта, попадающая в допустимый
диапазон синфазного напряжения шины. Без общей массы с машиной потенциал
устройства «плавает», и трансивер выходит за этот диапазон — связи не будет
либо она будет рваться.

Схема питания и земли

Отсюда и ответ про питание: **MCP2515 питается от Arduino**, а не от шины.
Шина CAN не несёт питания вообще, в ней только два сигнальных провода.

---

## Цепочка питания

```
+12 В (после зажигания) ──→ Mini360 ──→ 5.0 В ──→ Nano (вывод 5V)
                                                     │
масса кузова ───────────→ Mini360 ──→ GND ───────────┴──→ всё остальное
```

Ко всем модулям питание приходит **с Arduino**, а не отдельными проводами от
преобразователя. Так проще разводка и гарантированно одна земля.

| От | К | Примечание |
|---|---|---|
| +12 В после зажигания | Mini360 `IN+` | не от постоянного плюса, см. предупреждение |
| масса кузова | Mini360 `IN−` | |
| Mini360 `OUT+` | Nano `5V` | **не в `VIN`** |
| Mini360 `OUT−` | Nano `GND` | |

Вывод `VIN` рассчитан на 7–12 В и идёт через встроенный стабилизатор. Подавать
на него 5 В нельзя: стабилизатор потеряет на себе около полутора вольт, и
Arduino получит 3.5 В. Готовые 5 В подаются прямо на вывод `5V`.

---

## Полная распайка

### Nano → MCP2515

| Nano | MCP2515 |
|---|---|
| `5V` | `VCC` |
| `GND` | `GND` |
| `D10` | `CS` |
| `D11` | `SI` |
| `D12` | `SO` |
| `D13` | `SCK` |
| `D2` | `INT` |

`D11`, `D12`, `D13` — аппаратный SPI, переназначить их нельзя. `D2` нужен
именно потому, что это вход внешнего прерывания.

### Nano → OLED

| Nano | OLED |
|---|---|
| `5V` | `VCC` |
| `GND` | `GND` |
| `A4` | `SDA` |
| `A5` | `SCL` |

Провода паяются к плате дисплея напрямую, без гребёнки — она добавляет около
10 мм высоты, которых в корпусе нет.

### Nano → WS2812B

| Nano | WS2812B |
|---|---|
| `5V` | `VCC` / `5V` |
| `GND` | `GND` |
| `D6` | `DIN` |

Светодиод один. У ленты есть вход `DIN` и выход `DOUT` — подключается вход.

### Nano → KY-006 (зуммер)

| Nano | KY-006 |
|---|---|
| `D9` | `S` |
| `GND` | `−` |

Питание зуммеру не нужно: он пассивный, звук получается прямо из меандра на
сигнальном выводе. Средний вывод на большинстве плат не подключён.

### Nano → TTP-223 (задел, в прошивке не используется)

| Nano | TTP-223 |
|---|---|
| `5V` | `VCC` |
| `GND` | `GND` |
| `D3` | `I/O` |

### MCP2515 → автомобиль

| MCP2515 | Машина |
|---|---|
| `CANH` | CAN High шины PT-CAN |
| `CANL` | CAN Low шины PT-CAN |

Как найти пару и куда подключаться — в [field-test.md](field-test.md).

---

## Что выходит из корпуса

Через кабельный ввод ⌀7 идут **четыре провода**:

| Провод | Куда |
|---|---|
| +12 В | цепь после зажигания |
| GND | масса кузова |
| CAN H | витая пара PT-CAN |
| CAN L | витая пара PT-CAN |

CAN H и CAN L желательно свить между собой — так пара меньше ловит наводки.
Сечения хватит любого монтажного, ток мизерный.

---

## Потребление

| Узел | Ток при 5 В |
|---|---|
| Arduino Nano | ~20 мА |
| MCP2515 + TJA1050 | ~10 мА, кратко больше при передаче |
| OLED | ~15 мА |
| WS2812B, яркость 60/255 | ~10 мА в тревоге, иначе ~1 |
| TTP-223 | ~5 мА |
| **Итого** | **~60 мА** |

Со стороны 12 В это около 30 мА. У Mini360 предел 1.8 А — запас
многократный, греться ему не с чего.

---

## Два режима подключения

### На столе и при разведке шины

Arduino питается **от ноутбука по USB**, Mini360 и 12 В не участвуют вообще.
Но массу машины подключать всё равно нужно — ради общей точки отсчёта для
трансивера.

```
ноутбук USB ──→ Nano (питание)
масса машины ──→ Nano GND
CAN H / CAN L ──→ MCP2515
```

### После установки

USB отключён, питание идёт от машины:

```
+12 В после зажигания ──→ Mini360 ──→ Nano 5V
масса кузова ──────────→ Mini360 ──→ Nano GND
CAN H / CAN L ─────────────────────→ MCP2515
```

> **Не подключайте USB и 12 В одновременно.** На клонах Nano линия USB-питания
> и вывод `5V` связаны без развязки, и два источника начинают бороться друг с
> другом. Перед перепрошивкой снимайте питание с Mini360 — или хотя бы
> вынимайте предохранитель в цепи +12 В.

---

## Порядок первого включения

Каждый шаг проверяет одну вещь. Пропускать нельзя — половина пунктов
существует потому, что обратный порядок сжигает плату.

1. **Настроить Mini360 без нагрузки.** Подать на вход 12 В, покрутить
   подстроечник, добиться на выходе 5.0 В по мультиметру. Только после этого
   подключать Arduino. При обратном порядке на выходе может оказаться входное
   напряжение, и Nano вместе с дисплеем уходит в утиль за секунду.
2. **Проверить терминатор на MCP2515.** Между `CANH` и `CANL` обесточенного
   модуля не должно быть ~120 Ом. Если есть — выпаять, см.
   [field-test.md](field-test.md).
3. **Собрать всё, кроме CAN.** Питание, дисплей, зуммер, светодиод.
   Подать 5 В: дисплей должен показать экран с прочерками и `NO CAN`
   в жёлтой полосе — то есть логика работает, а шины пока нет.
4. **Подключить CAN.** При включённом зажигании прочерки должны смениться
   значениями в течение секунды.

Если на третьем шаге экран пуст — дело в питании или в I2C. Если на четвёртом
остаётся `NO CAN` — MCP2515 не поднялся: кварц, распайка SPI или терминатор.

---

## Предупреждения

### Питание только после зажигания

Контакт 16 колодки OBD и большинство силовых точек в салоне запитаны
**постоянно**. Устройство потребляет около 30 мА от 12 В и в режиме стоянки
не отключается.

У E90 суммарный ток покоя в спящем режиме укладывается примерно в 30–50 мА.
Наши 30 мА удваивают его: машина либо не уснёт как следует, либо посадит
аккумулятор за несколько дней стоянки.

Берите +12 В с цепи, которая обесточивается вместе с зажиганием. Инструкция
к серийному устройству того же назначения предлагает прикуриватель — но
**проверьте свой мультиметром**: на части машин передний прикуриватель запитан
постоянно, и тогда это ровно тот случай, которого мы избегаем. Критерий
простой: выключили зажигание — напряжение должно пропасть.

Если подходящей цепи рядом нет, ставьте выключатель и не забывайте им
пользоваться, но это заведомо хуже.

### Альтернатива: засыпать по тишине на шине

Есть способ обойтись **постоянным плюсом** и не сажать аккумулятор — гасить
устройство программно. Приём подсмотрен у самодельного дисплея на E90
(см. [references.md](references.md)): его блок включается по зажиганию и
выключается, когда шина сообщает об отсутствии ключа.

Нам для этого даже не нужно декодировать состояние ключа. **PT-CAN замолкает,
когда машина засыпает**, так что достаточно правила «нет кадров N секунд →
спать». Не зависит ни от шины, ни от расшифровки конкретных кадров.

Что для этого нужно в прошивке:

1. Считать время с последнего принятого кадра.
2. По превышении порога (разумно 30–60 с) погасить дисплей и светодиод, а
   MCP2515 перевести в спящий режим — у него есть команда `sleep`.
3. Сам ATmega328P усыпить в `SLEEP_MODE_PWR_DOWN` с пробуждением по
   прерыванию от вывода `INT` модуля MCP2515: тот умеет будить контроллер по
   приходу кадра.

В таком режиме потребление падает на порядки: сам MCP2515 в сне берёт
единицы микроампер, ATmega — тоже. Просыпается всё от первого же кадра,
когда машину открыли и шина ожила.

**В прошивке этого пока нет.** Требование питания после зажигания остаётся в
силе; засыпание — задел, если захочется упростить проводку.

### Полярность CAN

Перепутать `CANH` и `CANL` не смертельно — шина просто не поднимется, и на
экране останется `NO CAN`. Если пара найдена верно (около 60 Ом между
проводами при выключенном зажигании), а связи нет — поменяйте местами.

### Устройство передаёт в шину — один запрос в секунду

Раньше прошивка работала в `MCP_LISTENONLY` и физически не могла отправить ни
кадра. С появлением опроса температуры впуска режим сменён на `MCP_NORMAL`:
раз в секунду уходит запрос `30 0A 01` на адрес `0x600` (DME). Всё остальное
по-прежнему читается из широковещания пассивно.

Подробности и обоснование — в [diag-jobs.md](diag-jobs.md).

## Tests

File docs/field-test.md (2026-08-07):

# Разведка шины на машине

Пошаговая инструкция: от макетки до подключения к PT-CAN. Порядок именно
такой, потому что каждый шаг проверяет ровно одну вещь. Если пропустить и
сразу лезть в проводку, при отсутствии данных будет неясно, что виновато —
кварц, распайка, скорость шины или точка подключения.

Машина: **E90 318i 2011, N46B20, ZF 6HP19.**

---

## Шаг 0. Проверки на столе, до машины

### 0.1 Кварц на модуле MCP2515

Посмотрите маркировку на металлической банке кварца рядом с чипом MCP2515:
`8.000` или `16.000`.

В `platformio.ini` стоит:

```ini
-D MCP2515_CRYSTAL_MHZ=8
```

Если у вас 16 — поправьте на `16`. При неверном значении тайминги бит-рейта
считаются неправильно, и шина либо не откроется, либо посыплется мусором.
Это причина номер один, по которой «ничего не работает».

### 0.2 Терминатор 120 Ом — снять

На плате MCP2515 почти всегда напаян резистор 120 Ом между CAN H и CAN L.
Он нужен, когда шину строят с нуля, и **мешает при подключении к готовой**:
у исправной шины автомобиля уже есть два своих терминатора, суммарно 60 Ом.
Третий опускает сопротивление до 40 Ом, и обмен начинает сбоить.

На **обесточенном** модуле померьте мультиметром между клеммником CAN H и
CAN L. Увидите около 120 Ом — резистор на месте, выпаять (на части плат
вместо него перемычка, тогда просто перерезать).

### 0.3 Распайка Nano ↔ MCP2515

| MCP2515 | Arduino Nano |
|---|---|
| VCC | 5V |
| GND | GND |
| CS | D10 |
| SI | D11 (MOSI) |
| SO | D12 (MISO) |
| SCK | D13 |
| INT | D2 |

Модуль питается именно от **5 В**: трансиверу TJA1050 нужны пять вольт.

Дисплей, светодиод и зуммер для разведки не нужны — сканер выводит всё в
Serial. Можно не подключать.

### 0.4 Проверка, что прошивка заливается

Подключите Nano к Mac по USB и убедитесь, что порт появился:

```bash
ls /dev/cu.*
```

Должен быть `/dev/cu.wchusbserial*` или похожий. Если пусто — нужен драйвер
CH340: `brew install --cask wch-ch34x-usb-serial-driver`, потом перезагрузка.

Залейте сканер:

```bash
pio run -e sniffer -t upload
```

### 0.5 Проверка, что чип отвечает

Не подключая ничего к машине, откройте монитор:

```bash
pio device monitor
```

Ожидаемо: сканер отработает две переписи по 10 секунд и обе объявит немыми —
шины же нет. Это нормально.

**Важно другое:** если вместо этого появилось

```
MCP2515 init FAILED: check CS wiring and crystal
```

— значит Nano вообще не видит чип. Дальше идти бессмысленно: проверяйте
распайку SPI, питание модуля и кварц из шага 0.1.

---

## Шаг 1. Первое подключение — к OBD, ради проверки цепочки

Смысл шага: убедиться, что вся цепочка работает на настоящей машине, но в
самом безопасном месте — в штатном разъёме, ничего не разбирая и не втыкаясь
в проводку.

На вашей машине 2011 года на контактах 6/14 диагностическая шина **D-CAN**.
Широковещания там нет, поэтому перепись покажет тишину — **и это правильный
результат, а не поломка**. Проверяем мы вторую фазу: ответы на запросы.

Распиновка колодки OBD-II (стандартная, смотреть на разъём в машине):

| Контакт | Назначение |
|---|---|
| 6 | CAN High |
| 14 | CAN Low |
| 4 или 5 | масса |
| 16 | +12 В, постоянный |

Подключите: `6 → CANH` модуля, `14 → CANL` модуля, `4 → GND`.

Про землю, чтобы не было разночтений: **в устройстве она одна**. GND модуля
MCP2515 и GND Arduino — это один и тот же провод, они уже соединены при
распайке. Контакт 4 колодки цепляется к этой общей земле, то есть фактически
к `GND` Arduino.

CAN H и CAN L землёй **не являются** — это дифференциальная пара, соединять
их с массой нельзя. Масса нужна отдельно и обязательно: без общей точки
отсчёта с машиной потенциал устройства плавает, трансивер выходит за
допустимый диапазон и связи не будет.

Питание с контакта 16 сейчас брать не нужно — Nano питается от ноутбука по
USB. Как подключать питание после установки, описано в
[wiring.md](wiring.md).

Порядок действий:

1. Зажигание выключено, воткнули провода.
2. Включили зажигание (двигатель можно не заводить).
3. Запустили монитор:

```bash
pio device monitor
```

Монитор перезапускает плату при подключении, так что начало вывода вы
увидите. Полный цикл: 10 с + 10 с переписи, затем свип PID.

**Что должно получиться:**

```
== phase 1: silent census @ 100 kbit/s (K-CAN), 10 s ==
frames: 0   ~0/s   unique ids: 0
SILENT at this bitrate.
== phase 1: silent census @ 500 kbit/s (PT-CAN / D-CAN), 10 s ==
frames: 0   ~0/s   unique ids: 0
SILENT at this bitrate.
== phase 2: PID sweep 0x00..0xA0 @ 500 kbit/s ==
-> PID 00
   <- 0x7E8  06 41 00 BE 3F A8 13
-> PID 01
   <- 0x7E8  ...
```

Строки `<- 0x7E8` — это ответы двигателя. Если они пошли, значит **всё
железо и весь код работают**: кварц угадан, распайка верна, скорость верна.
Дальше можно спокойно идти к PT-CAN.

Если ответов нет вообще — вернитесь к шагу 0.1 (кварц) и 0.2 (терминатор).

Вывод этой фазы сохраните, он пригодится: там видно, какие стандартные PID
машина поддерживает, включая `0x5C` (масло двигателя) и `0x6C` (по одному из
источников — масло АКПП, не подтверждено).

---

## Шаг 2. Подключение к PT-CAN

Здесь начинается работа с проводкой, поэтому — аккуратно.

### Где искать

Конкретная точка для E9x / E8x / E7x, из инструкции к серийному устройству
того же назначения:

| | |
|---|---|
| Блок | **JBBF** (он же JBE, блок предохранителей и электроники) |
| Где | справа **под бардачком** |
| Разъём | **синяя фишка X14271** |
| Контакт 1 | PT-CAN **H**, провод синий/красный |
| Контакт 2 | PT-CAN **L**, провод красный |

Рядом на том же блоке стоит вторая фишка X14272 — не перепутайте, нужна
именно синяя X14271.

Цвета проводов приведены как дополнительная проверка: если на контакте 1
оказался не синий с красной полосой, остановитесь и перемерьте. У разных
годов и комплектаций возможны отличия.

### Проверка перед подключением

Даже с точной распиновкой стоит убедиться измерением: между контактами 1 и 2
при выключенном зажигании должно быть около **60 Ом**.

Это два штатных терминатора по 120 Ом, включённых параллельно. Ни на какой
другой паре в машине такого не будет — то есть измерение подтверждает, что
вы попали именно в шину CAN, а не в соседние контакты. Какая именно это
шина, скажет сканер.

Мерить лучше через пару минут после выключения зажигания, чтобы блоки
успели уснуть.

### Как подключаться

Не режьте провода. Варианты по возрастанию аккуратности:

- прокол изоляции щупом-иглой — быстро, но остаётся дырка;
- back-probe: тонкий щуп с тыльной стороны разъёма, рядом с проводом;
- переходник-разветвитель на нужный разъём, если найдёте под свой блок.

Полярность: перепутать CAN H и CAN L не смертельно — шина просто не откроется,
и перепись покажет тишину. Если на паре с ~60 Ом тишина на обеих скоростях —
поменяйте провода местами и повторите.

Массу по-прежнему берите с кузова или с контакта 4 колодки OBD.

### Запуск

Зажигание включено, лучше с заведённым двигателем — тогда вещают все блоки,
включая EGS с температурой масла коробки.

```bash
pio device monitor
```

**Что должно получиться:**

```
== phase 1: silent census @ 500 kbit/s (PT-CAN / D-CAN), 10 s ==
frames: 15234   ~1523/s   unique ids: 28
TRAFFIC -> broadcast bus. Hardware filters required.
id      count   data            signal
0x1D0   412     8B FF 6A C8 ...  <- [B] EngineData coolant/oil
0x0B5   205     00 00 .. .. 78   <- [P] EGS torque + ATF temp
...
markers: PT-CAN-only 1, K-CAN-only 0
=> PT-CAN. lib/PtCan decoders apply. ATF temp available.
```

Расшифровка меток: `[P]` — кадр встречается только на PT-CAN, `[K]` — только
на K-CAN, `[B]` — на обеих, потому что шлюз его ретранслирует.

Итоговая строка `=>` и говорит, куда вы попали.

---

## Что прислать мне

Скопируйте из монитора целиком:

1. Обе таблицы переписи (100 и 500 кбит/с) с итоговыми строками.
2. Вывод свипа PID с шага 1 — какие PID ответили.

По этому я смогу:

- подтвердить, что декодер температуры ATF (`0x0B5`) читает реальные байты
  верно — сейчас он проверен только по DBC, без данных с живой машины;
- найти топливо и температуру впуска среди неопознанных ID, если они там есть;
- настроить аппаратные фильтры MCP2515 под то, что реально приходит.

Если в таблице окажется больше 40 уникальных ID, сканер напишет
`WARNING: table full` — сообщите, я подниму лимит.

---

## Если что-то пошло не так

| Симптом | Наиболее вероятная причина |
|---|---|
| `MCP2515 init FAILED` | распайка SPI, питание модуля, неверный кварц |
| Тишина на обеих скоростях, но на OBD ответы шли | перепутаны CAN H и CAN L, либо это не шина |
| Мусорные ID, бессмысленные значения | неверный кварц (шаг 0.1) |
| Работает «через раз», сбоит при прогреве | не снят терминатор 120 Ом (шаг 0.2) |
| Порт не появляется в `/dev/cu.*` | нет драйвера CH340 |
| Монитор молчит | плата сброшена до открытия монитора — переоткройте |

Сканер работает в режиме `MCP_LISTENONLY` во время переписи: в шину машины
он в это время не передаёт ничего. Во второй фазе он шлёт стандартные
диагностические запросы — ровно то, что делает любой сканер за 10 долларов.

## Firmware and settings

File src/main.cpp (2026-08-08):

#include <Arduino.h>
#include <SPI.h>
#include <Wire.h>
#include <avr/wdt.h>
#include <EEPROM.h>

#include <FastLED.h>
#include <U8g2lib.h>
#include <mcp_can.h>

#include "Alerts.h"
#include "BtnLearn.h"
#include "Diag.h"
#include "Buttons.h"
#include "PtCan.h"
#include "Screen.h"
#include "pins.h"

// Page-режим U8g2: буфер 128 байт вместо 1024. Полнокадровый на Nano
// вместе с остальным не помещается.
static U8G2_SSD1306_128X64_NONAME_1_HW_I2C oled(U8G2_R0, U8X8_PIN_NONE);

static MCP_CAN can(PIN_CAN_CS);
static CRGB leds[NUM_LEDS];

static PtCan pt;
static Diag dg;

// Опрос впуска раз в секунду: чаще незачем, а шину лишний раз не трогаем.
static const uint16_t DIAG_PERIOD_MS = 1000;
static uint32_t diag_last_ms = 0;

static const uint16_t BLINK_MS = 400;

// --- кнопка руля ---

// Идентификатор кадра кнопок заранее неизвестен: на PT-CAN он у нас не
// подтверждён. Устройство находит его само при первом включении и хранит
// привязку в EEPROM. Подробности алгоритма — в lib/BtnLearn.
static const uint16_t EE_ADDR = 0;
static const uint8_t EE_MAGIC = 0xB7;   // менять при смене формата записи

static const uint16_t LEARN_BASELINE_MS = 15000;
static const uint16_t LEARN_HOLD_MS = 30000;
static const uint16_t LEARN_SAVED_MS = 2000;

static BtnLearn learner;
static BtnBinding binding;
static Button wheel_btn;

static LearnPhase learn_phase = LearnPhase::None;
static uint32_t learn_t0 = 0;
static ScreenId screen = ScreenId::All;

static void ee_load() {
  uint8_t magic = EEPROM.read(EE_ADDR);
  if (magic != EE_MAGIC) return;
  uint8_t lo = EEPROM.read(EE_ADDR + 1);
  uint8_t hi = EEPROM.read(EE_ADDR + 2);
  BtnBinding b;
  b.id = static_cast<uint16_t>(lo) | (static_cast<uint16_t>(hi) << 8);
  b.byte_idx = EEPROM.read(EE_ADDR + 3);
  b.mask = EEPROM.read(EE_ADDR + 4);
  // Пустая маска смысла не имеет — считаем запись битой.
  if (b.mask == 0) return;
  b.valid = true;
  binding = b;
}

static void ee_save(const BtnBinding& b) {
  EEPROM.update(EE_ADDR + 1, static_cast<uint8_t>(b.id & 0xFF));
  EEPROM.update(EE_ADDR + 2, static_cast<uint8_t>(b.id >> 8));
  EEPROM.update(EE_ADDR + 3, b.byte_idx);
  EEPROM.update(EE_ADDR + 4, b.mask);
  EEPROM.update(EE_ADDR, EE_MAGIC);   // магия пишется последней
}

static bool can_ok = false;
static Alert cur_alert = Alert::None;

// Кадры, которые нам нужны. У MCP2515 шесть аппаратных фильтров; заняты
// три, остальные пока дублируют последний. Три свободных — это запас под
// то, что найдёт разведка (температура впуска, топливо).
static const uint32_t kWanted[] = {
    ptcan::ID_EGS_TORQUE,  // 0x0B5 температура масла АКПП
    ptcan::ID_ENGINE_DATA, // 0x1D0 ОЖ и масло двигателя
    ptcan::ID_BATTERY,     // 0x3B4 напряжение
    diag::DME_RESP,        // 0x608 ответ DME на наш запрос впуска
};
static const uint8_t N_WANTED = sizeof(kWanted) / sizeof(kWanted[0]);

static void setup_can() {
  const uint8_t clk =
#if MCP2515_CRYSTAL_MHZ == 16
      MCP_16MHZ;
#else
      MCP_8MHZ;
#endif

  // PT-CAN — 500 кбит/с.
  can_ok = (can.begin(MCP_ANY, CAN_500KBPS, clk) == CAN_OK);
  if (!can_ok) return;

  // Без фильтров тут никак: PT-CAN даёт порядка полутора тысяч кадров в
  // секунду, у MCP2515 всего два приёмных буфера, и Nano разгребает их по
  // SPI. Переполнение было бы молчаливым — кадры просто терялись бы.
  // Маска 0x7FF означает точное совпадение всех 11 бит.
  can.init_Mask(0, 0, 0x07FF);
  can.init_Mask(1, 0, 0x07FF);

  // Во время обучения фильтры должны быть открыты: мы ещё не знаем, в каком
  // кадре живёт кнопка. Нулевая маска означает «пропускать всё».
  if (learn_phase != LearnPhase::None) {
    can.init_Mask(0, 0, 0x0000);
    can.init_Mask(1, 0, 0x0000);
  } else {
    // Буфер RXB0 обслуживают фильтры 0..1, RXB1 — фильтры 2..5.
    // Незанятый фильтр пропускал бы всё подряд, поэтому лишние дублируют
    // последний нужный ID. Найденный кадр кнопки занимает свободный слот.
    for (uint8_t i = 0; i < 6; ++i) {
      uint32_t id = kWanted[i < N_WANTED ? i : N_WANTED - 1];
      if (i == N_WANTED && binding.valid) id = binding.id;
      can.init_Filt(i, 0, id);
    }
  }

  // NORMAL, а не LISTENONLY: устройство опрашивает DME о температуре
  // впуска, а для этого нужно передавать. Это осознанная смена посадки —
  // до появления опроса прошивка физически не могла отправить ни кадра.
  // Запрос ровно один, раз в секунду; см. docs/diag-jobs.md.
  can.setMode(MCP_NORMAL);
  pinMode(PIN_CAN_INT, INPUT);
}

// Уровень кнопки обновляется только приходом её кадра. Сбрасывать его на
// каждом проходе loop() нельзя: кадры идут периодически, между ними уровень
// не меняется, и обнуление давало бы ложные отпускания.
static bool btn_level = false;

static void poll_rx() {
  const uint32_t now = millis();
  while (digitalRead(PIN_CAN_INT) == LOW) {
    // Тип диктует библиотека: INT32U — это unsigned long, а не uint32_t.
    // На AVR они совпадают, на 32-битных платформах нет.
    unsigned long id = 0;
    uint8_t len = 0, buf[8];
    if (can.readMsgBuf(&id, &len, buf) != CAN_OK) break;
    const uint16_t cid = static_cast<uint16_t>(id & 0x7FFul);

    pt.apply(cid, buf, len, now);
    dg.apply(cid, buf, len, now);

    if (learn_phase == LearnPhase::Baseline) {
      learner.observe_baseline(cid, buf, len);
    } else if (learn_phase == LearnPhase::Hold) {
      if (learner.observe_hunt(cid, buf, len)) {
        binding = learner.result();
        ee_save(binding);
        learn_phase = LearnPhase::Saved;
        learn_t0 = now;
      }
    } else if (binding.valid && cid == binding.id) {
      btn_level = BtnLearn::pressed(binding, cid, buf, len);
    }
  }
}

static void poll_diag() {
  const uint32_t now = millis();
  if (!can_ok || learn_phase != LearnPhase::None) return;
  if (now - diag_last_ms < DIAG_PERIOD_MS) return;
  diag_last_ms = now;

  uint8_t req[8];
  Diag::build_request(diag::INTAKE_PAYLOAD, diag::INTAKE_PAYLOAD_LEN, req);
  can.sendMsgBuf(diag::DME_REQ, 0, 8, req);
}

static void update_alerts() {
  const uint32_t now = millis();
  const PtCanData& d = pt.data();

  cur_alert = alerts::evaluate(d.coolant_c, PtCan::fresh(d.coolant_ms, now),
                               d.atf_c, PtCan::fresh(d.atf_ms, now));

  // Желаемое состояние светодиода: 0 погашен, 1 красный (двигатель),
  // 2 оранжевый (коробка). Медленное мигание — период BLINK_MS.
  uint8_t want = 0;
  if (cur_alert != Alert::None && (now / BLINK_MS) % 2)
    want = (cur_alert == Alert::CoolantHot) ? 1 : 2;

  // ВАЖНО: FastLED.show() на AVR запрещает прерывания на всё время
  // передачи. Вызов на каждом проходе loop() держал бы процессор с
  // выключенными прерываниями почти постоянно: начинает отставать millis(),
  // а на нём висит вся логика протухания данных, ломается tone() и
  // страдает приём по I2C. Поэтому дёргаем только при смене состояния —
  // это пара раз в секунду вместо тысяч.
  static uint8_t shown = 0xFF;
  if (want != shown) {
    shown = want;
    fill_solid(leds, NUM_LEDS,
               want == 0 ? CRGB::Black
                         : (want == 1 ? CRGB::Red : CRGB::OrangeRed));
    FastLED.show();
  }

  static Alert prev = Alert::None;
  if (cur_alert != Alert::None && prev != cur_alert) {
    tone(PIN_BUZZER, cur_alert == Alert::CoolantHot ? 2000 : 1500, 200);
  }
  prev = cur_alert;
}

static void poll_learn() {
  if (learn_phase == LearnPhase::None) return;
  const uint32_t now = millis();

  switch (learn_phase) {
    case LearnPhase::Baseline:
      if (now - learn_t0 >= LEARN_BASELINE_MS) {
        learn_phase = LearnPhase::Hold;
        learn_t0 = now;
      }
      break;

    case LearnPhase::Hold:
      // Нажатие ловится в poll_rx; сюда попадаем только если не дождались.
      if (now - learn_t0 >= LEARN_HOLD_MS) {
        learn_phase = LearnPhase::Failed;
        learn_t0 = now;
      }
      break;

    case LearnPhase::Saved:
    case LearnPhase::Failed:
      if (now - learn_t0 >= LEARN_SAVED_MS) {
        learn_phase = LearnPhase::None;
        // Обучение шло с открытыми фильтрами; теперь можно сузить приём
        // до нужных кадров и добавить туда найденную кнопку.
        setup_can();
      }
      break;

    default:
      break;
  }
}

static void poll_button() {
  if (!binding.valid || learn_phase != LearnPhase::None) return;
  if (wheel_btn.update(btn_level, millis()) == BtnEvent::Click) {
    screen = static_cast<ScreenId>(
        (static_cast<uint8_t>(screen) + 1) %
        static_cast<uint8_t>(ScreenId::COUNT));
  }
}

// Вся вёрстка живёт в lib/Screen на C-API u8g2 — тот же код гоняет
// симулятор на хосте (см. sim/), поэтому картинка не расходится с реальной.
static void draw() {
  const uint32_t now = millis();
  const PtCanData& d = pt.data();

  ScreenData sd;
  sd.screen = screen;
  sd.learn = learn_phase;
  sd.learn_secs = (learn_phase == LearnPhase::Baseline)
                      ? static_cast<uint8_t>((LEARN_BASELINE_MS -
                                              (now - learn_t0)) / 1000)
                      : 0;
  sd.can_ok = can_ok;
  sd.alert = cur_alert;

  sd.coolant_c = d.coolant_c;
  sd.coolant_ok = PtCan::fresh(d.coolant_ms, now);
  sd.atf_c = d.atf_c;
  sd.atf_ok = PtCan::fresh(d.atf_ms, now);
  sd.oil_c = d.oil_c;
  sd.oil_ok = PtCan::fresh(d.oil_ms, now);
  sd.volts_mv = d.volts_mv;
  sd.volts_ok = PtCan::fresh(d.volts_ms, now);
  sd.iat_c = dg.data().iat_c;
  sd.iat_ok = Diag::fresh(dg.data().iat_ms, now);

  // Топливо остаётся пустым: KOMBI не на PT-CAN, а масштаб ответа
  // STATUS_TANKINHALT в SGBD не задокументирован. См. docs/diag-jobs.md.
  sd.fuel_ok = false;
  sd.tanks_ok = false;

  screen_draw(oled.getU8g2(), sd);
}

void setup() {
  pinMode(PIN_BUZZER, OUTPUT);

  oled.begin();
  Wire.setClock(400000);

  FastLED.addLeds<WS2812B, PIN_LEDS, GRB>(leds, NUM_LEDS);
  FastLED.setBrightness(60);
  fill_solid(leds, NUM_LEDS, CRGB::Black);
  FastLED.show();

  ee_load();
  // Привязки нет — значит первое включение, уходим в обучение.
  if (!binding.valid) {
    learn_phase = LearnPhase::Baseline;
    learn_t0 = millis();
    learner.reset();
  }

  setup_can();

  // Сторожевой таймер включается последним: инициализация дисплея и
  // MCP2515 не должна его тревожить. Устройство живёт в машине без
  // присмотра, зависший блок там никто не перезагрузит.
  //
  // Безопасно именно потому, что плата на новом загрузчике (Optiboot,
  // board = nanoatmega328new): он сбрасывает флаг WDRF и снимает таймер
  // при старте. Старый загрузчик после срабатывания WDT уходил в
  // бесконечную перезагрузку.
  wdt_enable(WDTO_2S);
}

void loop() {
  wdt_reset();

  poll_rx();
  poll_diag();
  poll_learn();
  poll_button();
  update_alerts();

  static uint32_t draw_ms = 0;
  const uint32_t now = millis();
  if (now - draw_ms >= 100) {
    draw_ms = now;
    draw();
  }
}

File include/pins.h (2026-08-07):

#pragma once

// Распиновка Arduino Nano V3.0 (ATmega328P).
//
// Занято аппаратно и трогать нельзя:
//   D11 MOSI, D12 MISO, D13 SCK  — SPI к MCP2515
//   A4 SDA, A5 SCL               — I2C к OLED (0x3C)

// --- MCP2515 (CAN) ---
static const uint8_t PIN_CAN_CS = 10;
static const uint8_t PIN_CAN_INT = 2;  // INT0, нужен именно 2 или 3

// --- Адресный светодиод WS2812B ---
// В сборке используется один. Количество почти не влияет на память:
// 3 байта RAM на диод, тогда как сама FastLED стоит ~3 КБ флеша.
static const uint8_t PIN_LEDS = 6;
static const uint8_t NUM_LEDS = 1;

// --- Пассивный зуммер KY-006 ---
// tone() на AVR всегда занимает Timer2 независимо от пина.
static const uint8_t PIN_BUZZER = 9;

// --- Резерв под расширение ---
// Сейчас не используется. Сенсорные кнопки TTP-223: выход активен
// ВЫСОКИМ уровнем, подтяжка не нужна. BME280 садится на ту же шину I2C
// (адрес 0x76 или 0x77), отдельных ног не требует.
static const uint8_t PIN_BTN[4] = {3, 4, 5, 7};
static const uint8_t NUM_BTNS = 4;

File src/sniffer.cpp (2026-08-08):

// Диагностический инструмент. Собрать и залить:
//   pio run -e sniffer -t upload && pio device monitor
//
// ГЛАВНЫЙ ВОПРОС, НА КОТОРЫЙ ОН ОТВЕЧАЕТ: к какой шине вы подключились.
// У E90 три кандидата, и на глаз они не различаются:
//   K-CAN   100 кбит/с — кузов, приборка, баки, кнопки руля
//   PT-CAN  500 кбит/с — мотор, EGS, температура масла АКПП
//   D-CAN   500 кбит/с — диагностика, молчит пока не спросят
//
// Фаза 1 — ПЕРЕПИСЬ, дважды по 10 секунд: на 100 и на 500 кбит/с.
//   Слушает молча (MCP_LISTENONLY), в шину ничего не уходит. Считает кадры,
//   собирает словарь уникальных ID и сверяет его с маркерами, у которых
//   известна принадлежность к шине. Печатается только итоговая таблица:
//   сырой дамп на живой PT-CAN — это полторы-две тысячи кадров в секунду,
//   Serial на 115200 таким потоком захлебнётся.
//
//   Тишина на обеих скоростях -> D-CAN, работает только опрос запросами.
//   Трафик -> смотрите вердикт по маркерам внизу таблицы.
//
// Фаза 2 — СВИП PID на 500 кбит/с. Перебирает стандартные PID режима 01
//   (0x00..0xA0) и печатает ответы. Диапазон расширен до 0xA0: DBC-mega-merge
//   упоминает PID 0x6C как температуру масла АКПП (не подтверждено).
//
// Для BMW-специфичных данных на PT-CAN есть адресный UDS-канал:
//   DME  запрос 0x600 -> ответ 0x608
//   EGS  запрос 0x604 -> ответ 0x60C   (адаптации и калибровки коробки)
//   DSC  запрос 0x612 -> ответ 0x61A
// Сервис 0x22 с нужным идентификатором данных шлётся туда же.

#include <Arduino.h>
#include <SPI.h>
#include <mcp_can.h>

#include "pins.h"

static MCP_CAN can(PIN_CAN_CS);

static const uint32_t REQ_ID = 0x7DF;
static const uint32_t CENSUS_MS = 10000;
static const uint16_t STEP_MS = 150;

// Словарь ID. 40 записей с запасом: на PT-CAN у E90 обычно
// несколько десятков уникальных идентификаторов.
static const uint8_t MAX_IDS = 40;

struct Seen {
  uint16_t id;
  uint16_t count;
  uint8_t len;
  uint8_t data[8];
};

static Seen tbl[MAX_IDS];
static uint8_t n_ids = 0;
static uint32_t total_frames = 0;
static uint16_t overflow_ids = 0;  // сколько ID не влезло в таблицу

// Маркеры шин. 'P' встречается только на PT-CAN, 'K' — только на K-CAN,
// 'B' есть на обеих (DME вещает, шлюз ретранслирует). По набору сразу
// понятно, куда вы подключились. Определения из DBC-mega-merge.
struct Known {
  uint16_t id;
  char bus;
  const char* name;
};

static const Known kKnown[] = {
    {0x0B5, 'P', "EGS torque + ATF temp"},
    {0x0BA, 'P', "TransmissionData gear"},
    {0x198, 'P', "GearSelectorSwitch"},
    {0x349, 'K', "FuelLevel left/right"},
    {0x2CA, 'K', "OutsideTemp"},
    {0x1D6, 'K', "SteeringButtons"},
    {0x0AA, 'B', "AccPedal/RPM"},
    {0x1D0, 'B', "EngineData coolant/oil"},
    {0x3B4, 'B', "BatteryVoltage"},
};
static const uint8_t N_KNOWN = sizeof(kKnown) / sizeof(kKnown[0]);

static const Known* known_entry(uint16_t id) {
  for (uint8_t i = 0; i < N_KNOWN; ++i) {
    if (kKnown[i].id == id) return &kKnown[i];
  }
  return nullptr;
}

static void record(uint16_t id, uint8_t len, const uint8_t* d) {
  ++total_frames;
  for (uint8_t i = 0; i < n_ids; ++i) {
    if (tbl[i].id == id) {
      ++tbl[i].count;
      tbl[i].len = len;
      for (uint8_t k = 0; k < len && k < 8; ++k) tbl[i].data[k] = d[k];
      return;
    }
  }
  if (n_ids >= MAX_IDS) {
    ++overflow_ids;
    return;
  }
  tbl[n_ids].id = id;
  tbl[n_ids].count = 1;
  tbl[n_ids].len = len;
  for (uint8_t k = 0; k < len && k < 8; ++k) tbl[n_ids].data[k] = d[k];
  ++n_ids;
}

static void print_hex(uint8_t v) {
  if (v < 0x10) Serial.print('0');
  Serial.print(v, HEX);
}

static void reset_table() {
  n_ids = 0;
  total_frames = 0;
  overflow_ids = 0;
}

static void census(const __FlashStringHelper* label) {
  Serial.print(F("== phase 1: silent census @ "));
  Serial.print(label);
  Serial.println(F(", 10 s =="));
  const uint32_t t0 = millis();
  while (millis() - t0 < CENSUS_MS) {
    if (digitalRead(PIN_CAN_INT) != LOW) continue;
    // INT32U из библиотеки — это unsigned long, а не uint32_t.
    unsigned long id = 0;
    uint8_t len = 0, buf[8];
    if (can.readMsgBuf(&id, &len, buf) != CAN_OK) continue;
    record(static_cast<uint16_t>(id & 0x7FFul), len, buf);
  }

  Serial.print(F("frames: "));
  Serial.print(total_frames);
  Serial.print(F("   ~"));
  Serial.print(total_frames / (CENSUS_MS / 1000));
  Serial.print(F("/s   unique ids: "));
  Serial.println(n_ids);

  if (n_ids == 0) {
    Serial.println(F("SILENT at this bitrate."));
    return;
  }

  // Сортируем по убыванию частоты: периодические кадры всплывают наверх,
  // а редкие события оседают вниз. Выбором, n не больше 40.
  for (uint8_t i = 0; i + 1 < n_ids; ++i) {
    uint8_t mx = i;
    for (uint8_t j = i + 1; j < n_ids; ++j)
      if (tbl[j].count > tbl[mx].count) mx = j;
    if (mx != i) {
      Seen t = tbl[i];
      tbl[i] = tbl[mx];
      tbl[mx] = t;
    }
  }

  Serial.println(F("TRAFFIC -> broadcast bus. Hardware filters required."));
  Serial.println(F("id\tcount\tdata\t\tsignal"));

  uint8_t hits_pt = 0, hits_k = 0;
  for (uint8_t i = 0; i < n_ids; ++i) {
    Serial.print(F("0x"));
    Serial.print(tbl[i].id, HEX);
    Serial.print(F("\t"));
    Serial.print(tbl[i].count);
    Serial.print(F("\t"));
    for (uint8_t k = 0; k < tbl[i].len; ++k) {
      print_hex(tbl[i].data[k]);
      Serial.print(' ');
    }
    const Known* k = known_entry(tbl[i].id);
    if (k) {
      if (k->bus == 'P') ++hits_pt;
      if (k->bus == 'K') ++hits_k;
      Serial.print(F("\t<- ["));
      Serial.print(k->bus);
      Serial.print(F("] "));
      Serial.print(k->name);
    }
    Serial.println();
  }

  Serial.print(F("markers: PT-CAN-only "));
  Serial.print(hits_pt);
  Serial.print(F(", K-CAN-only "));
  Serial.println(hits_k);
  if (hits_pt > hits_k) {
    Serial.println(F("=> PT-CAN. lib/PtCan decoders apply. ATF temp available."));
  } else if (hits_k > hits_pt) {
    Serial.println(F("=> K-CAN. lib/KCan applies. No ATF temp on this bus."));
  } else {
    Serial.println(F("=> inconclusive. Compare ids against the DBC by hand."));
  }
  if (overflow_ids) {
    Serial.print(F("WARNING: table full, ids dropped: "));
    Serial.println(overflow_ids);
  }
}
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

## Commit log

2026-08-07 Бортовой дисплей E90 на PT-CAN: первый рабочий срез
    Пассивно слушает моторную шину PT-CAN (500 кбит/с) и выводит на OLED
    128x64 температуры ОЖ, масла двигателя и масла АКПП плюс напряжение
    бортсети. При перегреве двигателя (>110 C) или коробки (>130 C для
    ZF 6HP19) мигает светодиодом и пищит зуммером.
    Целевая машина: BMW E90 318i 2011 LCI, N46B20, АКПП ZF 6HP19.
    Устройство только слушает: MCP_LISTENONLY, в шину машины ничего не
    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
2026-08-07 Инструкция по разведке шины на машине
    docs/field-test.md — пошаговый порядок работ от макетки до подключения
    к PT-CAN. Шаги выстроены так, чтобы каждый проверял ровно одну вещь:
    кварц и терминатор на столе, затем колодка OBD как безопасная проверка
    всей цепочки целиком, и только потом врезка в проводку.
    Ключевое в шаге с OBD: на машине 2011 года там D-CAN, перепись покажет
    тишину, и это правильный рез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
2026-08-07 Эскиз корпуса под 3D-печать
    docs/enclosure.md — компоновка на 84 x 62 x 26 мм: две печатные детали,
    четыре винта M3, доступ к USB без разборки. Четыре чертежа: план дна,
    разрез по высоте, крышка, порядок сборки.
    Форму задало то, что MCP2515 (40 x 28) и Nano (45 x 18) вместе занимают
    почти всю площадь дна, а дисплей 27 x 27 не помещается ни на одну боковую
    стенку высотой 26 мм. Отсюда плоская шайба с дисплеем в крышке.
    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
2026-08-07 Убрать .DS_Store из репозитория
    Служебный файл macOS попал в предыдущий коммит вместе с чертежами.
    Удалён из индекса и добавлен в .gitignore, чтобы не возвращался.
2026-08-07 Площадка под сенсорную кнопку TTP-223 в крышке
    Задел на будущее переключение экранов: в прошивке кнопка не задействована,
    но переделывать напечатанную крышку дороже, чем предусмотреть карман сразу.
    Главное в узле — отверстия нет. TTP-223 ёмкостной и срабатывает сквозь
    пластик, поэтому наружу ничего не выходит: ни кнопки, ни щели под пыль.
    Взамен стенку над пятном надо локально утоньшит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
2026-08-07 Лунка под палец вместо кольца, инструкция по распайке
    Маркер сенсорной кнопки переделан по предложению владельца: вместо
    выступающего кольца — лунка под палец с наружной стороны крышки. Решение
    лучше исходного, потому что одна деталь делает две работы. Лунка даёт
    тактильную метку, в которую палец сам попадает, и одновременно является
    тем самым утоньшением: 2.5 мм крышки минус 1.3 м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
2026-08-07 Параметрическая модель корпуса для OpenSCAD
    cad/enclosure.scad — обе печатные детали одним файлом. Формат выбран
    текстовый: исходник живёт в git, диффится и правится параметрами после
    того, как будут промерены реальные платы.
    Крышка увеличена с 2.5 до 3.0 мм. Карман под дисплей глубиной 1.8 оставлял
    над окном 0.7 мм — три слоя при 0.2. При 3.0 остаётся 1.2, ровно столько
    же, сколько под лункой сенсора, кото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
    [enclosure.scad]
2026-08-07 Не дёргать FastLED.show() каждый проход, сторожевой таймер
    FastLED.show() вызывался безусловно в update_alerts(), то есть тысячи раз
    в секунду. На AVR он запрещает прерывания на всё время передачи в ленту,
    так что процессор почти всё время проводил с закрытыми прерываниями.
    Симптомы были бы неочевидными: отстающий millis(), на котором висит вся
    логика протухания данных, кривой tone() и порча приёма по I2C.
    Тепер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
    [enclosur4e.scad, enclosure-layout.obj, enclosure.scad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]
2026-08-07 Точная точка подключения PT-CAN на E9x
    Из инструкции к серийному устройству того же назначения: блок JBBF (он же
    JBE) справа под бардачком, синяя фишка X14271, контакт 1 — PT-CAN H, провод
    синий/красный, контакт 2 — PT-CAN L, провод красный. Рядом стоит вторая
    фишка X14272, её легко перепутать.
    Это закрывает пробел, который до сих пор оставался в field-test.md: раньше
    там были только названия блоков и способ опоз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
2026-08-07 Три экрана и обучение кнопки руля
    Экраны листаются кнопкой на руле: обзорный, температура ОЖ крупно с
    иконкой термометра, напряжение бортсети крупно.
    Идентификатор кадра кнопок MFL заранее неизвестен: в захватах DBC-mega-merge
    он есть только для K-CAN (0x1D6), а PT-CAN-логов нет вовсе. Инструкция к
    серийному устройству того же назначения показала выход — не прошивать ID, а
    искать его на месте. Реал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
2026-08-08 Телеграммы диагностических запросов из SP-Daten
    Идентификаторы диагностических данных BMW публично не документированы, и мы
    планировали нащупывать их, слушая трафик Tool32. Оказалось, что не нужно:
    телеграмма запроса лежит прямо в байткоде job'а в SGBD и видна в
    дизассемблере как move S1,{$82,$FF,$F1,$21,$0A}.
    Метод проверен на job'е, где идентификатор продублирован в комментарии:
    у KOMB87 STATUS_TANKINHALT написано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
2026-08-08 Справка по компонентам, правка устаревшего утверждения
    docs/components.md — по каждому из закупленных модулей: назначение,
    подводные камни, статус в сборке. Собрано из того, что выяснилось по ходу
    работы, чтобы можно было продолжить в другом диалоге, не поднимая всю
    переписку.
    Заодно исправлено место, которое стало неверным после добавления опроса
    впуска: в wiring.md был раздел "Устройство ни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
